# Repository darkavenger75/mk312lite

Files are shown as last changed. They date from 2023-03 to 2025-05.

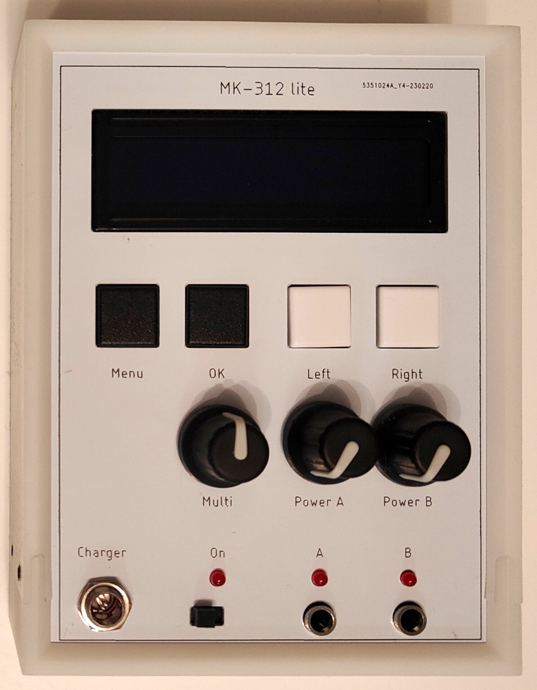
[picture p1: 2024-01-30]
images/mk312lite_case.jpg

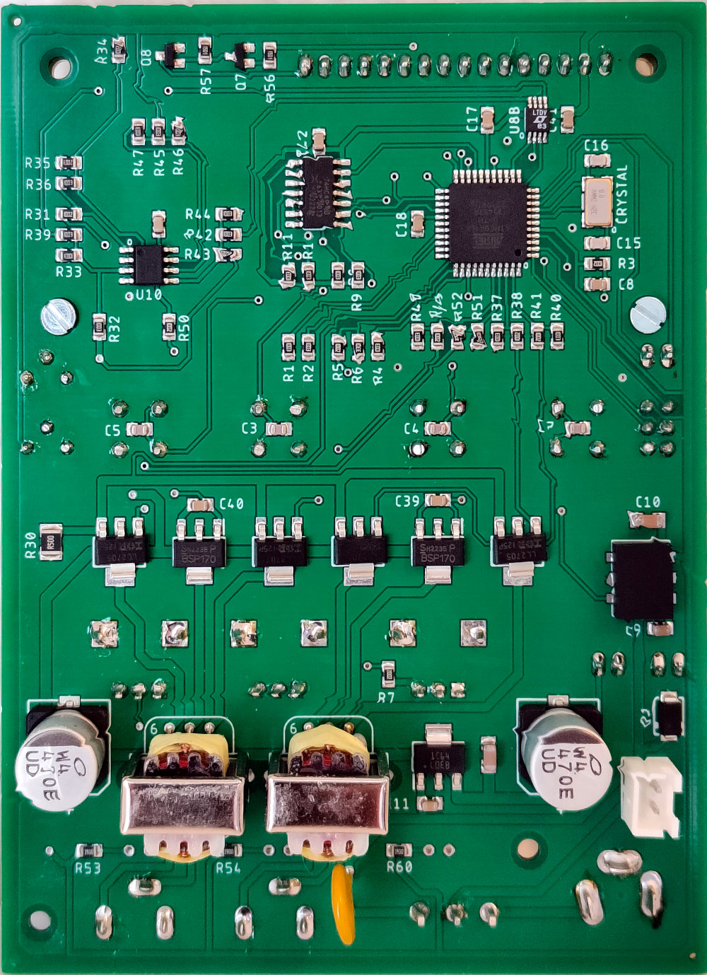
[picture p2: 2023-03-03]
images/mk312lite_pcb_back.jpg

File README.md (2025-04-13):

# mk-312 lite

## Introduction

A smaller, lighter, cheaper and easier to assemble version of the mk-312 with most of its functionality

- LiFePO4 instead of Pb battery
- 90 x 120 mm single PCB design
- Most components SMT (JLCPCB will do most of the work)
- No inputs, though

## Board ordering instructions

PCB
- Default settings by JLCPCB work fine. Feel free to choose different color, etc. Lead-free recommended for the sake of the environment.

Front panel
- 1.2 mm aluminium, black or white. 

Assembly
- Economic, Bottom side, as many PCBs as you wish. "Confirm Parts Placement" recommended. 
- Automatic selection of parts after uploading BOM and CPL worked well, but better check for errors. 
- Check part placement and rotation, esp. ATmega, transistors and 5V DC/DC converter (K7805).  

## Parts ordering information

You will in addition require all pin-through-hole parts, they are included in the BOM (V4), though. Do not forget the buttom covers and knobs for the potentiometers. 
In addition, you will have to order
- A 12V 2Ah LiFePo4 4-cell battery with BMS and connector matching the one you used on the board. I got mine from Eremit in Germany. You can use a 3-cell LiPo battery pack instead (there is a LDO voltage regulator on the 9V rail), but the R5/R6 voltage divider must be adjusted to avoid incorrect low battery warning/shutdown.
- A matching external CHARGER for your battery pack with 5.5/2.1 mm connector, center positive. Do NOT just connect a power supply without current limiter.   

## Board assembly Instructions

- The two transformers, battery connector and polyfuse (if not SMT) go to the bottom of the PCB (or the front panel will not fit).
- Best shorten the spindels of the pots beforehand, if you bought the 20 mm version. Also shorten/remove the taps.  
- The connectors and LEDs are best soldered with the front panel attached such that they fit neatly into the respective holes. 
- Ensure polarity of your battery pack and charger is correct, or things may get fried. 

## Firmware

The firmware has not been modified, for instructions see the "firmware" folder. 

## Case

The front panel goes directly on top of the PCB. Use washers on the pots to level the front panel as required.  
Bottom closes with plain aluminum panel.  
A simple 3D printed case - two halves which close by 4 pins or headless screws - can be found in the "case" directory.

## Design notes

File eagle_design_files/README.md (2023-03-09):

EAGLE board, schematic and front panel for the mk-312 lite fun box.

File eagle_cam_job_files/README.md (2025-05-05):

Files for PCB production and SMT assembly by JLCPCB 

Gerber file:           JLC_gerber.zip

BOM, bottom, SMT only: JLC_BOM.csv

Pick-and-place:        JLC_CPL.csv

Make sure to check placement/orientation of SMT components when ordering an already assembled board!

Full BOM:              mk312lite_V2_full_BOM.csv 

Anything that has an entry in the "Description" column is pin-through-hole and has to be ordered separately. 

Front panel, Gerber:   JLC_gerber_front.zip (fitting a 71*24 mm display)

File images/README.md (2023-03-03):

Photos of the PCB and the assembled device.

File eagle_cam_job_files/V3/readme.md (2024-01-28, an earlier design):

## Update
- BOM edited to include JLCPCB part numbers such that automatic part selection should work from the start
- CPL edited to fix rotation of components
- Some extended parts replaced by basic parts for lower cost. Further cost reduction by replacing the logic-level MOSFETs IRLL2705 by AO3400 possible. 
- Display brightness pot removed due to being ineffective

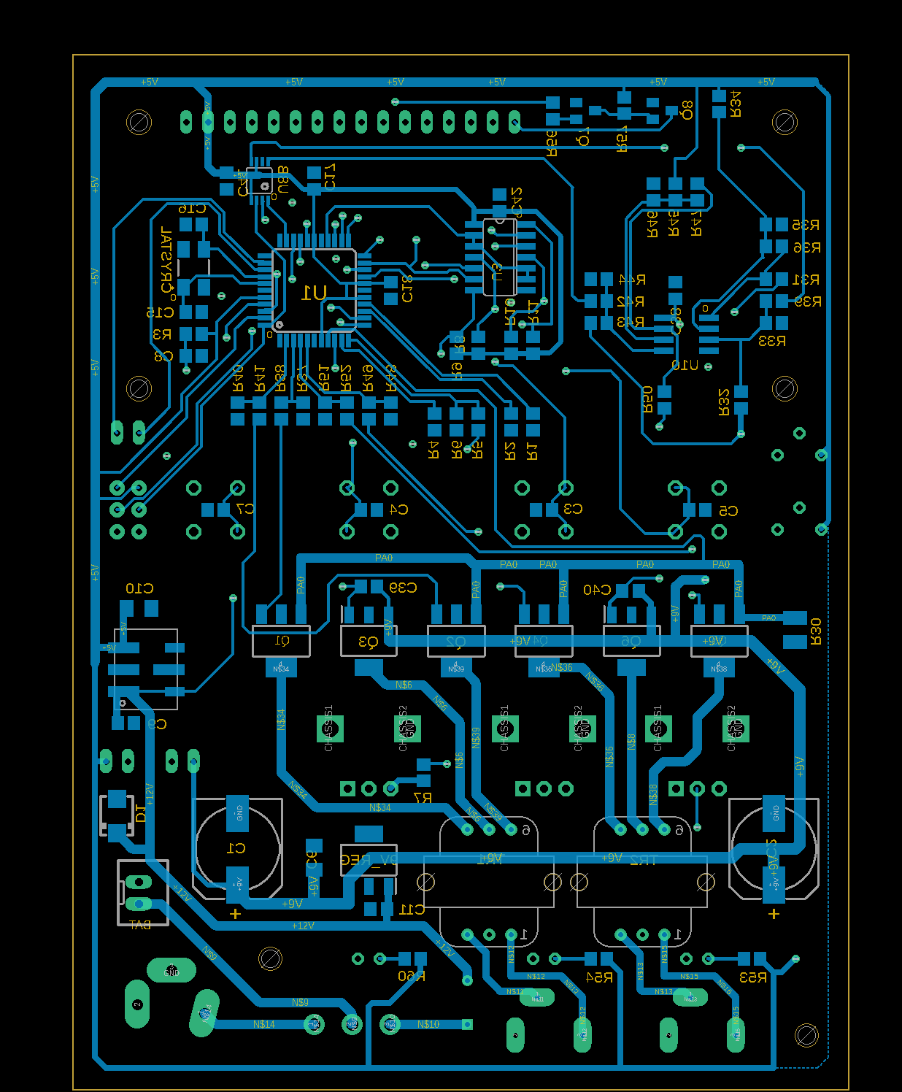
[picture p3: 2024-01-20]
eagle_design_files/mk312lite_V2_Bottom.png

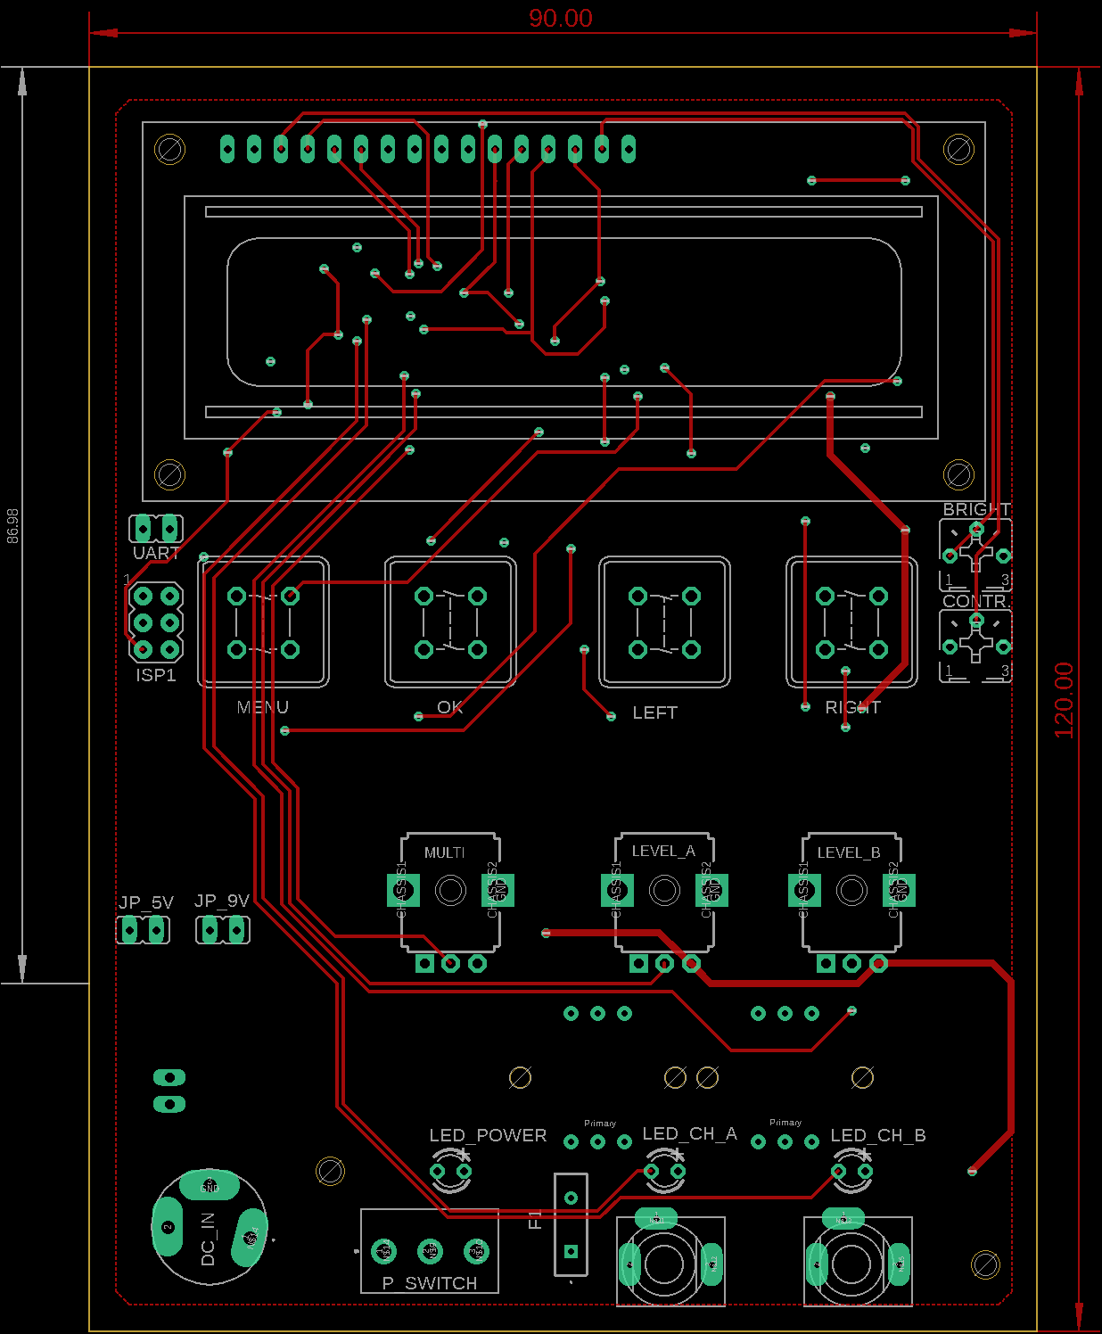
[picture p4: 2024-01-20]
eagle_design_files/mk312lite_V2_Top.png

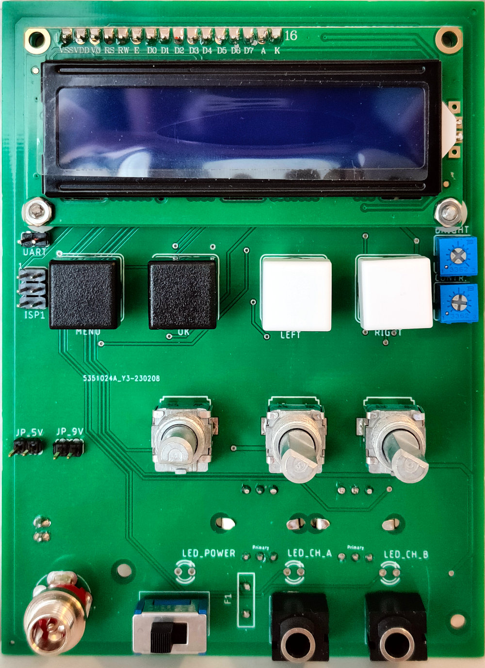
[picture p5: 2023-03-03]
images/mk312lite_pcb_front.jpg

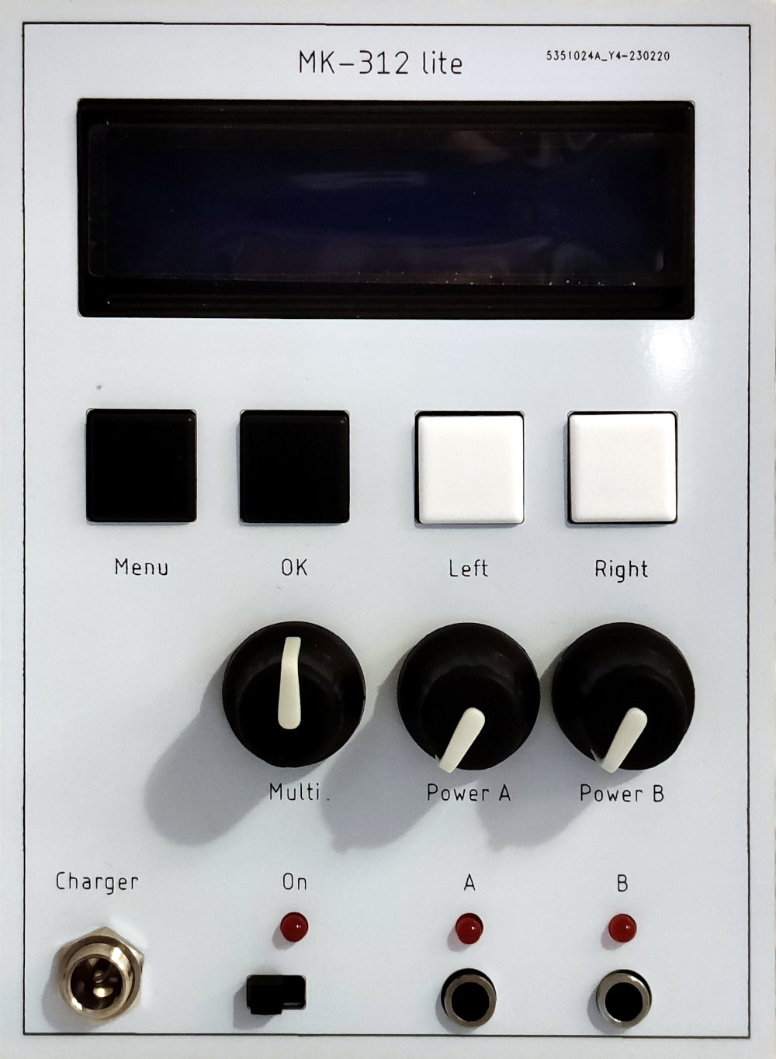
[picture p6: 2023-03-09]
images/mk312lite_front.jpg

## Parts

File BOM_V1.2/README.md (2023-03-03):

Old BOM of version 1.2. Might contain additional useful information on the required PTH components.

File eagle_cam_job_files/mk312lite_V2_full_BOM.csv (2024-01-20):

Part | Value | Device | Package | Description
9V_REG | LM2940IMP-9.0/NOPB | LM2940IMP-9.0_NOPB | SOT230P700X180-4N
BAT | B2B-XH-A-GU | JST-XH-02-PIN-LONG-PAD | JST-XH-02-PACKAGE-LONG-PAD | JST XH Connector 2 Pin (battery connector)
C1 | 470uF | CPOL-EU150CLZ-1010 | 150CLZ-1010
C2 | 470uF | CPOL-EU150CLZ-1010 | 150CLZ-1010
C3 | 100pF | C-EUC0805 | C0805
C4 | 100pF | C-EUC0805 | C0805
C5 | 100pF | C-EUC0805 | C0805
C6 | 22uF | C-EUC1206 | C1206
C7 | 100pF | C-EUC0805 | C0805
C8 | 0.1uF | C-EUC0805 | C0805
C9 | 10uF | C-EUC0805 | C0805
C10 | 22uF | C-EUC1206 | C1206
C11 | 0.47uF | C-EUC0805 | C0805
C15 | 20pF | C-EUC0603 | C0603
C16 | 20pF | C-EUC0603 | C0603
C17 | 0.1uF | C-EUC0805 | C0805
C18 | 0.1uF | C-EUC0805 | C0805
C38 | 0.1uF | C-EUC0805 | C0805
C39 | 0.1uF | C-EUC0805 | C0805
C40 | 0.1uF | C-EUC0805 | C0805
C41 | 0.1uF | C-EUC0805 | C0805
C42 | 0.1uF | C-EUC0805 | C0805
CHAN_A | PJ-301C | PC-301C | PJ-301C | 1/8“ phone connector, mono, XKB
CHAN_B | PJ-301C | PC-301C | PJ-301C | 1/8“ phone connector, mono, XKB
CONTR. | 10k | TRIM_US-B25P | B25P | Bourns 3362P
CRYSTAL | 8MHZ | X2-SMD-5.0X3.2X1.3MM | Seed
D1 | S1M | S1M | SMA
DC_IN | PC721A | PC721A | PC721A | 5.5 / 2.1 mm DC connector
F1 | RHEF100 | RHEF100-2 | RHEF1002 | PTC Resettable Fuse 1A 30V
ISP1 | AVRISP-6 | AVRISP-6 | AVRISP | AVR ISP HEADER
JP_5V | +5V | JP1E | JP1 | JUMPER (optional)
JP_9V | +9V | JP1E | JP1 | JUMPER (optional)
LCD1 | HD44780LCD-1602 | HD44780LCD-1602 | LCD1602 | HD44780 LCD, 2 rows, 16 chars, e.g. Adafruit 181
LED_CH_A | OUTPUT A | LED3MM | LED3MM | LED
LED_CH_B | OUTPUT B | LED3MM | LED3MM | LED
LED_POWER | POWER | LED3MM | LED3MM | LED
LEFT | LEFT/DOWN | DTE6K | DTE6K | ITT SWITCH, buttom cover: BTND610F
LEVEL_A | RK09L1140A2U 10k | 9MM_SNAP-IN_POT_CHASSIS | 9MM_SNAP-IN_POT | 9mm vertical snap-in pot, Alpha / Panasonic style, knob BA761 / alternative RK09L1140A5L
LEVEL_B | RK09L1140A2U 10k | 9MM_SNAP-IN_POT_CHASSIS | 9MM_SNAP-IN_POT | 9mm vertical snap-in pot, Alpha / Panasonic style, knob BA761 / alternative RK09L1140A5L
MENU | MENU | DTE6K | DTE6K | ITT SWITCH, buttom cover: BTND600F
MULTI | RK09L114001E 10k | 9MM_SNAP-IN_POT_CHASSIS | 9MM_SNAP-IN_POT | 9mm vertical snap-in pot, Alpha / Panasonic style, knob BA761
OK | OK | DTE6K | DTE6K | ITT SWITCH, buttom cover: BTND600F
P_SWITCH | 8SS1012-Z | 8SS1012-Z | 8SS1012Z | NIDEC COPAL ELECTRONICS - 8SS1012-Z - SLIDE SWITCH, SPDT, 6A, 125VAC, TH
Q1 | IRLL2705P | N-HEXFET-2D_SOT232-IRLL2705 | SOT223
Q2 | IRLL2705P | N-HEXFET-2D_SOT232-IRLL2705 | SOT223
Q3 | BSP170PH6327 | IRFL9014TRPBF | SOT230P700X180-4N
Q4 | IRLL2705P | N-HEXFET-2D_SOT232-IRLL2705 | SOT223
Q5 | IRLL2705P | N-HEXFET-2D_SOT232-IRLL2705 | SOT223
Q6 | BSP170PH6327 | IRFL9014TRPBF | SOT230P700X180-4N
Q7 | MMBT3904 | MMBT3904LT1-NPN-SOT23-BEC | SOT23-BEC
Q8 | MMBT3904 | MMBT3904LT1-NPN-SOT23-BEC | SOT23-BEC
R1 | 100k | R-EU_R0805 | R0805
R2 | 100k | R-EU_R0805 | R0805
R3 | 10K | R-EU_R0805 | R0805
R4 | 100k | R-EU_R0805 | R0805
R5 | 10K | R-EU_R0805 | R0805
R6 | 3.3K | R-EU_R0805 | R0805
R7 | 20k | R-EU_R0805 | R0805
R8 | 100k | R-EU_R0805 | R0805
R9 | 100k | R-EU_R0805 | R0805
R10 | 100k | R-EU_R0805 | R0805
R11 | 100k | R-EU_R0805 | R0805
R12 | 100R | R-EU_R0805 | R0805
R30 | 1R | R-EU_R1206 | R1206
R30_2 | 1R | R-EU_R1206 | R1206
R31 | 100K | R-EU_R0805 | R0805
R32 | 100K | R-EU_R0805 | R0805
R33 | 100K | R-EU_R0805 | R0805
R34 | 100K | R-EU_R0805 | R0805
R35 | 200K | R-EU_R0805 | R0805
R36 | 100K | R-EU_R0805 | R0805
R37 | 100K | R-EU_R0805 | R0805
R38 | 10K | R-EU_R0805 | R0805
R39 | 10K | R-EU_R0805 | R0805
R40 | 100K | R-EU_R0805 | R0805
R41 | 10K | R-EU_R0805 | R0805
R42 | 100K | R-EU_R0805 | R0805
R43 | 100K | R-EU_R0805 | R0805
R44 | 100K | R-EU_R0805 | R0805
R45 | 100K | R-EU_R0805 | R0805
R46 | 200K | R-EU_R0805 | R0805
R47 | 100K | R-EU_R0805 | R0805
R48 | 100K | R-EU_R0805 | R0805
R49 | 10K | R-EU_R0805 | R0805
R50 | 10K | R-EU_R0805 | R0805
R51 | 100K | R-EU_R0805 | R0805
R52 | 10K | R-EU_R0805 | R0805
R53 | 390 | R-EU_R0805 | R0805
R54 | 390 | R-EU_R0805 | R0805
R56 | 1.5K | R-EU_R0805 | R0805
R57 | 1.5K | R-EU_R0805 | R0805
R60 | 390 | R-EU_R0805 | R0805
RIGHT | RIGHT/UP | DTE6K | DTE6K | ITT SWITCH, buttom cover: BTND610F
TR1 | 42TL004 | 42TL023 | 42TL | Xicon Micro-Mini EI-12 Audio Transformers 42TL/42TC/42TM Series
TR2 | 42TL004 | 42TL023 | 42TL | Xicon Micro-Mini EI-12 Audio Transformers 42TL/42TC/42TM Series
U$1 | K7805MT-500R4 | K7805MT-500R4 | DFN
U1 | ATMEGA16A | MEGA16-A | TQFP44
U3 | 4066D | 4066D | SO14
U8B | LTC1661 | LTC1661IMS8 | MSOP8
U10 | LM358D | LM358D | SO08
UART |  | JP1E | JP1 | JUMPER (optional)

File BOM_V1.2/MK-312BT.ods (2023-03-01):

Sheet: INFO
MK-312 BT V1.2 Information
Github Project Home : https://git.io/vMPVF
About
INFO is this Google Sheet - the latest copy of this document lives at http://tinyurl.com/mk312bt-info or https://goo.gl/Ia0wMW
FULLBOM consists of all items - sorted for sanity. Enter the number of units you want to produce in the top row and it will math for you.
MOUSERBOM1 contains items in FULL_BOM available from mouser and we select the "recommended" options . This BOM is for 1 UNIT.
NONMOUSER is a list of all the parts you cant get from Mouser with links to where you can get them from
RAWBOM is the output Eagle generates for the V1.1 schematic. This is used for cross checking the other documents.
MK-312BT V1.2 - Hardware Improvements over original ET-312B
1) Line input modified for matched frequency and level response on left and right channels.
2) Link I/O circuitry replaced with MAX-232CPE For better compatibility (True RS-232 Levels)
3) Provisions for Bluetooth radio, Radio takes over Link I/O when nothing is in the jack
4) New one piece front panel design where LCD, buttons, potentiometers, and LEDs are on the sub panel. Jacks and power switch on mainboard. Cleaner looking design with controls and jacks on 3/4" centers
5) Remote input added to facilitate DC response into B channel without compromising line audio input characteristics. Tip is voltage coming from remote 0-2 volts, Ring supplies 2 volts from a resistor divider internal to the unit. Sleeve is ground. The Remote is meant for the Audio 1 & 2 modes. External potentiometer and push button recommended for remote. Other SPST type of items can be used such as motion detectors with dry contact output or mercury switches.
6) Support for tri polar (+, GND, -) toys on the output channels
MK-312BT Hardware Jumper Settings
1) JP6 and JP7 [DISABLED BY DEFAULT]
Enabling JP6 and JP7 allow the use of tripolar (+, GND, -) toys on the corresponding channels by connecting the center tap of the transformer to the stereo jack
WARNING : ENABLING JP6 and JP7 will cause mono plug toys to short the transformer !!
MK-312BT Hardware Assembly Notes / Tips - PLEASE READ -
1) Trim Potentiometer knobs to correct length
2) Use black permanent marker to black out front panel hole walls
3) Cut the tabs off of the base of the pots so the board sits flush with the display facade
4) To correctly fit LCD - solder header to LCD board first. Next insert LCD panel into front panel daughter board. Then put screws on front panel facade and finger tighten M2.5 screws first. Adjust positions as needed so everything lines up and sits well. Finally soldering LCD header to front panel daughter board.
5) Make sure Pin 32 (LED2) on the HC-05 module is actually soldered and making connection to the ZS-040 break out board or "Radio" LED may not function on the front panel
6) Be very careful not to bridge pins when soldering the LM 2941 (U14). Apply heat to 1 pad only and carefully apply solder. If a bridge occurs - remove the IC, clean the pads throughly with flux and solder wick and then retry. Pins 2 and 3 can be bridged because they are both ground. Ensure that no other pins are bridged. Check with multimeter continuity tester for bridges before power on!
8) Make sure to check the orientation of all electrolytic caps. (+) indicates the positive and a solid white "|" indicates the negative .
9) MAKE SURE YOUR POWER PLUG IS CENTER POSITIVE OR THINGS WILL GO BADLY. If you fuck up and plug in a reversed polarity supply - replace electrolytic caps C1 and C4.
10) Please remember to adjust the LCD contrast potentiometer - if incorrectly set the unit and backlight will power on but the interface will not be displayed.
11) Place transformers with P facing the output jacks (yes we are using the transformers "backwards" if you follow orientation given in the transformer datasheet )
12)Trim pins of 4066 IC (U3) Socket on the front panel board flush before soldering so buttons can clear. If the buttons still interfere, carefully disassemble the button and cut off the bit of the plastic housing that interferes with the 4066 IC socket pins.
Changes made in buttshock-et312-frankenbutt f005 over original ET 312B V1.5/V1.6 firmware https://git.io/vMoHG
F005 Patches the following in addition to the stock firmware
1) changeversion: changes startup message from v1.6 to f005
2) unifyboxes: allow 1.5 and 1.6 boxes to share the same firmware
3) removerandomxor: box will always pick 0 as it's xor communication key
4) serialdumpmemory: box will allow serial to dump more of the flash memory on request
5) fixknobscaling: A and B levels now display smoothly 0-99 with no missing numbers
6) newmenu; adds a new sub menu "More Options", moves Link Slave to that menu
7) hookmain: adds a new mode "Random 3" kind of a combination of torment and random1 to the new options menu, adds a new mode "Random 4" which turns on with a random mode for 40ish seconds, then off for 20ish seconds
Modifying and Flashing Firmware onto ET312-BT
1) We are using an external 8mhz crystal instead of the internal RC oscillator that the original uses. We need to set the fuses to enable this. LOW FUSE : 0xFF HIGH FUSE : 0xDB
2) A patched version of buttshock-et312-frankenbutt-f005 is recommended .
3) Obtain or modify a copy of the firmware and flash the result onto the AVR.
5) If you dont want to use an external crystal - we need to set the calibration byte for the internal oscillator. If programming a blank chip you first need to read the calibration bytes of that part (i.e. using avrdude -t “dump calibration” the fourth byte is the calibration byte for 8MHz or use atmel studio to read the oscillator calibration byte). Then program that byte into 0x3fff in your firmware. These bytes will differ on different chips even from the same batch. The firmware reads that byte to set OSCCAL on startup. If the byte is inaccurate various problems and failures will occur related to timing, interrupts, and serial communication. Just use an external crystal dammit.
Errata and and Changes made from V1.0 to V1.1
1) C25 and C27 are mislabeled on the board, 1000pF is the correct value
2) R20 and R21 are mislabeled on the board, 100K is the correct value
3) R14 and R15 are mislabeled on the board, 1K is the correct value
4) R20 and R21 are mislabeled on the board, 20K is the correct value
5) Do not populate R9 100K
6) Do not populate R1B 12K
Errata and and Changes made from V1.1 to V1.2
1) Fixed routing error on display board.
2) Removed JP3 because pointless.
3) Changed size of electrolytics to make things fit a bit nicer.
Images of V1.2 MK 312BT
TODO : Changes to make for V1.3 MK 312BT
1) LM 2941 footprint to make it easier to solder without bridging
2) Move 4066 IC to better place.

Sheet: FULLBOM
Number of Units Produced : | 1
Designator | Description | Quantity per Unit | Total Quantity | Supplier | Supplier Part Number | Alternate Part | Notes
R55 | RES 47R | 1 | 1 | Mouser | 660-MF1/4DC47R0F
R53,R54,R59,R60 | RES 390R | 4 | 4 | Mouser | 660-MF1/4DCT52R3900F
C10,C11,C12,C13,C14,C17,C18,C19,C2,C21,C22,C23,C24,C26,C28,C29,C3,C32,C37,C38,C39,C40,C41,C42,C43,C44,C9 | CAP 0.1uF (0.1" spacing) 50V | 27 | 27 | Mouser | 80-C320C104K5R
R30 | RES 0.5R 1/2W | 1 | 1 | Mouser | 660-CF1/2CT52RR50J
R2 | RES 1.2K | 1 | 1 | Mouser | 660-MF1/4DCT52R1201F
R18, R56,R57 | RES 1.5K | 3 | 3 | Mouser | 660-MF1/4DCT52R1501F
C4,C5 | 1000uF 16V minimum | 2 | 2 | Mouser | 647-UPW1E102MPD6
R10,R20,R21,R27,R28,R29,R3,R31,R32,R33,R34,R36,R37,R40,R42,R43,R44,R45,R47,R48,R51 | RES 100K | 21 | 21 | Mouser | 660-MF1/4DC1003F
R38,R39,R41,R49,R5,R50,R52,R58 | RES 10K | 8 | 8 | Mouser | 660-MF1/4DCT52R1002F | 660-MF1/4DC1002F
C8 | CAP 10uF | 1 | 1 | Mouser | 647-USV1H100MFD1TP
C1 | CAP 10uF CER | 1 | 1 | Mouser | 810-FG11X7R1H106KRT6 |  | Ceramic Cap in case of reverse voltage dc supply
R1A | RES 12K | 1 | 1 | Mouser | 660-MF1/4DCT52R1202F
C15,C16 | CAP 18pF | 2 | 2 | Mouser | 80-C315C180J1G
F1 | 1A POLYFUSE | 1 | 1 | Mouser | 650-LVR100S
R14,R15,R19, | RES 1K | 3 | 3 | Mouser | 660-MF1/4DCT52R1001F
R12,R23,R25,R26 | RES 1M | 4 | 4 | Mouser | 660-MF1/4DCT52R1004F
D1 | DIODE 1N4004 | 1 | 1 | Mouser | 621-1N4004
D2,D3 | DIODE 1N4148 | 2 | 2 | Mouser | 512-1N4148
C25,C27 | CAP 1nF (0.1" spacing) | 2 | 2 | Mouser | 80-C315C102K1G
C20,C30,C31,C33,C34,C35,C36 | CAP 1uF (0.1" spacing) | 7 | 7 | Mouser | 80-C315C105K3R
R35,R46 | RES 200K | 2 | 2 | Mouser | 660-MF1/4DCT52R2003F
R11,R16,R17,R22,R24,R4 | RES 20K | 6 | 6 | Mouser | 660-MF1/4DCT52R2002F
J10,J11 | PAK100/2500-24 - 2425- 3M WALL HEADER | 2 | 2 | Mouser | 517-N2524-6002RB
Q7,Q8 | TRANS. 2N3904 | 2 | 2 | Mouser | 512-2N3904BU
R6 | RES 3.3K | 1 | 1 | Mouser | 660-MF1/4DCT52R3301F
R7,R8,R9 | RES 4.7K | 3 | 3 | Mouser | 660-MF1/4DCT52R4701F
U3 | CD4066N | 1 | 1 | Mouser | 595-CD4066BE
TR1,TR2 | 42TL004 | 2 | 2 | Mouser | 42TL004-RC
C6,C7 | CAP 470uF 16V | 2 | 2 | Mouser | 647-UHE1E471MPD
R13 | RES 47K | 1 | 1 | Mouser | 660-MF1/4DCT52R4702F
U13 | VREG 7805T | 1 | 1 | Mouser | 511-L7805CV | 511-L7805ACP | Alternate part is better thermally
U11,U12 | VREG 7809TV | 2 | 2 | Mouser | 511-L7809CV
XTAL1 | 8MHZ XTAL HC-49S | 1 | 1 | Mouser | 717-9B-8.000MEEJ-B
U1 | ATMEGA 16P | 1 | 1 | Mouser | 556-ATMEGA16A-PU | http://www.digikey.com/short/3fb4z5
LCD1 | LCD HD44780LCD-1602 | 1 | 1 | Mouser | 763-0216K1Z-NSW-BBW | 763-0216K1Z-NSW-FBW
Q3,Q6 | MOSFET IRF9Z24 | 2 | 2 | Mouser | 942-IRF9Z24NPBF
Q1,Q2,Q4,Q5 | MOSFET IRL520N | 4 | 4 | Mouser | 942-IRL520NPBF
JP1 | ISP 6 PIN | 1 | 1 | Mouser | 571-5-146254-3
U14 | LM2941 | 1 | 1 | Mouser | 926-LM2941CT/NOPB
U2 | LM324N | 1 | 1 | Mouser | 595-LM324N | 595-LM324NE3
U10,U4 | LM358N | 2 | 2 | Mouser | 512-LM358N
U8A (OPTIONAL - RECOMMEND USING U8B INSTEAD) | MAX548 | 0 | 0 | Mouser | 700-MAX548ACPA |  | For V1.5 and below firmware.We suggest using U8B LTC1661 purchased from Digikey (see below)
LED1,LED2,LED3,LED4 | 5MM LED | 4 | 4 | Mouser | 606-4304H1
U9 | MAX232 | 1 | 1 | Mouser | 700-MAX232CPE
SOCKET FOR U2,U3 | DIL 14 IC SOCKET | 2 | 2 | Mouser | 517-4814-3004-CP
SOCKET FOR U9 | DIL 16 IC SOCKET | 1 | 1 | Mouser | 517-4816-3004-CP
SOCKET FOR U1 | DIL 40 IC SOCKET | 1 | 1 | Mouser | 575-11041640410010
SOCKET FOR U10,U4,U8(A/B) | DIL 8 IC SOCKET | 4 | 4 | Mouser | 571-1-2199298-2
JP6,JP7 | 2x1 SIP HEADER 0.1" | 2 | 2 | Mouser | 571-5-146285-2
JUMPER | 0.1" JUMPER | 3 | 3 | Mouser | 571-382811-6
VR1, VR2 | ALPS 9mm 10K Pot | 2 | 2 | Mouser | 688-RK09L1140A2U
VR3 | ALPS 9mm 10K Dual Gang Pot | 1 | 1 | Mouser | 688-RK09L1240A12
VR4 | Bourns 3362P 10K Pot | 1 | 1 | Mouser | 3362P-1-103LF
S1,S2,S3,S4 | Buttons | 4 | 4 | Mouser | 611-D6C90F2LFS
J2,J3,J4,J5,J6,J7 | 3.5mm stereo jack | 6 | 6 | Mouser | 806-STX-3100-5NB
J8 | 2.1/5.5mm DC jack | 1 | 1 | Mouser | 490-PJ-002A
S5 | Toggle Switch with safety actuator | 1 | 1 | Mouser | 611-7101K2AV2BE | 611-7101K2AV2QE
J9 | Radio Header | 1 | 1 | Mouser | 538-90147-1206
PACTEC Case | Case | 1 | 1 | Mouser | 616-63025-510-000 | Suggest buying directly from PACTEC or sourcing a compatible case elsewhere http://bit.ly/2iuAHbB . UK SOURCE : http://uk.rs-online.com/web/p/consoles-desktop-enclosures/1047312/
Gray button covers | Button Cover | 2 | 2 | Mouser | 611-BTND610F | 611-BTND690F
White button covers | Button Cover | 2 | 2 | Mouser | 611-BTND600F
LCD HEADER | LCD Header | 1 | 1 | Mouser | 710-61301611121
KNOB | Potentiometer KNOB | 3 | 3 | Mouser | 450-BA761
BAT1 (Recommended Option) | Lead Acid Battery 2.5AH | 1 | 1 | Mouser | 547-PS-1220 | UK SOURCE http://uk.rs-online.com/web/p/lead-acid-rechargeable-batteries/5375444/
BAT1 (Option) | Lead Acid Battery 1.4AH | 0 | 0 | Mouser | 547-PS-1212
BAT 1 LUGS | Lugs For Connecting to BAT1 | 2 | 2 | Mouser | 534-8291 |  | Crimp on Lugs for Battery
Power Supply 15V (Option) | 15V, > 1A , 5.5MM OD Plug | 0 | 0 | Mouser | 709-GST25U15-P1J
Power Supply 18 V (Recommended Option) | 18V, 1A , 5.5MM OD Plug | 1 | 1 | Mouser | 709-GST18U18-P1J |  | Suggest using 18V version to give linear regulator a bit more headroom . 15V will *just barely* work
IDC connectors for ribbon cable | Ribbon Cable Connector(or buy a ready made cable) | 2 | 2 | Mouser | 517-8924 |  | Suggest sourcing a ready made cable . See misc hardware below
24 conductor ribbon cable | Bare Ribbon Cable (or buy a ready made cable) | 1 | 1 | Mouser | 517-3365/24-100 |  | See above.
Radio | HC-05 Bluetooth Module | 1 | 1 | Amazon | HC-05 (multiple amazon vendors) |  | http://amzn.to/2iiOXz6
U8B | LTC1661 (For V1.6 and above firmware) | 1 | 1 | Digikey | LTC1661CN8#PBF-ND |  | This is the suggested DAC
J1 T Connector (Deans Connector)- DNF (Unless you want to , then F away) | 12V Battery Connector | 1 | 1 | Hobbyking | SKU: 015000231-0 |  | http://bit.ly/2jpP4gQ
MISC HARDWARE
Ribbon Cable 24 pin, 2.54mm pitch IDC. | Ribbon Cable | 1 | 1 | Amazon | B01BGNLPX0 |  | http://amzn.to/2jp34ay
#4 x 1/4" sheet metal screw (Main board to case) | Screw | 2 | 2 | McMaster-Carr | 90190A106 |  | http://bit.ly/2jCJuVR
M2.5 x 20mm socket head screw (Front panel screws) | Screw | 6 | 6 | McMaster-Carr | 91290A108 |  | http://bit.ly/2jhEohH
M2.5 nut (Front panel nut) | Screw | 22 | 22 | McMaster-Carr | 90591A270 |  | http://bit.ly/2jpf0Jq
18 Gauge Wire : | Battery Leads (quantity ft) | 5 | 5 | McMaster-Carr | 8054T15 |  | http://bit.ly/2jCHwER
Heat Shrink | Heat Shrink Tubing | 1 | 1 | McMaster-Carr | 7496K43 |  | http://bit.ly/2jYteSl

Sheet: MOUSERBOM1
Designator | Description | Quantity per Unit | Supplier | Supplier Part Number | Mfg Part Number | Alternate Part
R55 | RES 47R | 1 | Mouser | 660-MF1/4DC47R0F | MF1/4DC47R0F
R53,R54,R59,R60 | RES 390R | 4 | Mouser | 660-MF1/4DCT52R3900F | MF1/4DCT52R3900F
C10,C11,C12,C13,C14,C17,C18,C19,C2,C21,C22,C23,C24,C26,C28,C29,C3,C32,C37,C38,C39,C40,C41,C42,C43,C44,C9 | CAP 0.1uF (0.1" spacing) 50V | 27 | Mouser | 80-C320C104K5R | C320C104K5R5TA
R30 | RES 0.5R 1/2W | 1 | Mouser | 660-CF1/2CT52RR50J | CF1/2CT52RR50J
R2 | RES 1.2K | 1 | Mouser | 660-MF1/4DCT52R1201F | MF1/4DCT52R1201F
R18, R56,R57 | RES 1.5K | 3 | Mouser | 660-MF1/4DCT52R1501F | MF1/4DCT52R1501F
C4,C5 | 1000uF 16V minimum | 2 | Mouser | 647-UPW1E102MPD6 | UPW1E102MPD6
R10,R20,R21,R27,R28,R29,R3,R31,R32,R33,R34,R36,R37,R40,R42,R43,R44,R45,R47,R48,R51 | RES 100K | 21 | Mouser | 660-MF1/4DC1003F | MF1/4DC1003F
R38,R39,R41,R49,R5,R50,R52,R58 | RES 10K | 8 | Mouser | 660-MF1/4DC1002F | MF1/4DC1002F | 660-MF1/4DCT52R1002F
C8 | CAP 10uF | 1 | Mouser | 647-USV1H100MFD1TP | USV1H100MFD1TP
C1 | CAP 10uF CER | 1 | Mouser | 810-FG11X7R1H106KRT6 | FG11X7R1H106KRT06
R1A | RES 12K | 1 | Mouser | 660-MF1/4DCT52R1202F | MF1/4DCT52R1202F
C15,C16 | CAP 18pF | 2 | Mouser | 80-C315C180J1G | C315C180J1G5TA
F1 | 1A POLYFUSE | 1 | Mouser | 650-LVR100S | LVR100S
R14,R15,R19, | RES 1K | 3 | Mouser | 660-MF1/4DCT52R1001F | MF1/4DCT52R1001F
R12,R23,R25,R26 | RES 1M | 4 | Mouser | 660-MF1/4DCT52R1004F | MF1/4DCT52R1004F
D1 | DIODE 1N4004 | 1 | Mouser | 621-1N4004 | 1N4004-T
D2,D3 | DIODE 1N4148 | 2 | Mouser | 512-1N4148 | 1N4148
C25,C27 | CAP 1nF (0.1" spacing) | 2 | Mouser | 80-C315C102K1G | C315C102K1G5TA
C20,C30,C31,C33,C34,C35,C36 | CAP 1uF (0.1" spacing) | 7 | Mouser | 80-C315C105K3R | C315C105K3R5TA
R35,R46 | RES 200K | 2 | Mouser | 660-MF1/4DCT52R2003F | MF1/4DCT52R2003F
R11,R16,R17,R22,R24,R4 | RES 20K | 6 | Mouser | 660-MF1/4DCT52R2002F | MF1/4DCT52R2002F
J10,J11 | PAK100/2500-24 - 2425- 3M WALL HEADER | 2 | Mouser | 517-N2524-6002RB | N2524-6002RB
Q7,Q8 | TRANS. 2N3904 | 2 | Mouser | 512-2N3904BU | 2N3904BU
R6 | RES 3.3K | 1 | Mouser | 660-MF1/4DCT52R3301F | MF1/4DCT52R3301F
R7,R8,R9 | RES 4.7K | 3 | Mouser | 660-MF1/4DCT52R4701F | MF1/4DCT52R4701F
U3 | CD4066N | 1 | Mouser | 595-CD4066BE | CD4066BE
TR1,TR2 | 42TL004 | 2 | Mouser | 42TL004-RC | 42TL004-RC
C6,C7 | CAP 470uF 16V | 2 | Mouser | 647-UHE1E471MPD | UHE1E471MPD
R13 | RES 47K | 1 | Mouser | 660-MF1/4DCT52R4702F | MF1/4DCT52R4702F
U13 | VREG 7805T | 1 | Mouser | 511-L7805CV | L7805CV | 511-L7805ACP
U11,U12 | VREG 7809TV | 2 | Mouser | 511-L7809CV | L7809CV
XTAL1 | 8MHZ XTAL HC-49S | 1 | Mouser | 717-9B-8.000MEEJ-B | 9B-8.000MEEJ-B
U1 | ATMEGA 16P | 1 | Mouser | 556-ATMEGA16A-PU | ATMEGA16A-PU | 556-ATMEGA16L-8PU ELSE SEE DIGIKEY ON NONMOUSER
LCD1 | LCD HD44780LCD-1602 | 1 | Mouser | 763-0216K1Z-NSW-BBW | NHD-0216K1Z-NSW-FBW-L | 763-0216K1Z-NSW-FBW
Q3,Q6 | MOSFET IRF9Z24 | 2 | Mouser | 942-IRF9Z24NPBF | IRF9Z24NPBF
Q1,Q2,Q4,Q5 | MOSFET IRL520N | 4 | Mouser | 942-IRL520NPBF | IRL520NPBF
JP1 | ISP 6 PIN | 1 | Mouser | 571-5-146254-3 | 5-146254-3
U14 | LM2941 | 1 | Mouser | 926-LM2941CT/NOPB | LM2941CT/NOPB
U2 | LM324N | 1 | Mouser | 595-LM324NE3 | LM324NE3 | 595-LM324N
U10,U4 | LM358N | 2 | Mouser | 512-LM358N | LM358N
U8A | MAX548 (For V1.5 and below firmware) suggest using LTC1661 purchased from Digikey (see end of sheet) | 0 | Mouser | 700-MAX548ACPA | MAX548ACPA+
LED1,LED2,LED3,LED4 | 5MM LED | 4 | Mouser | 606-4304H1 | 4304H1
U9 | MAX232 | 1 | Mouser | 700-MAX232CPE | MAX232CPE
SOCKET FOR U2,U3 | DIL 14 IC SOCKET | 2 | Mouser | 517-4814-3004-CP | 4814-3004-CP
SOCKET FOR U9 | DIL 16 IC SOCKET | 1 | Mouser | 517-4816-3004-CP | 4816-3004-CP
SOCKET FOR U1 | DIL 40 IC SOCKET | 1 | Mouser | 575-11041640410010 | 110-41-640-41-001000
SOCKET FOR U10,U4,U8(A/B) | DIL 8 IC SOCKET | 4 | Mouser | 571-1-2199298-2 | 1-2199298-2
JP6,JP7 | 2x1 SIP HEADER 0.1 | 2 | Mouser | 571-5-146285-2 | 5-146285-2
VR1, VR2 | ALPS 9mm 10K Pot | 2 | Mouser | 688-RK09L1140A2U | RK09L1140A2U
VR3 | ALPS 9mm 10K Dual Gang Pot | 1 | Mouser | 688-RK09L1240A12 | RK09L1240A12
VR4 | Bourns 3362P 10K Pot | 1 | Mouser | 3362P-1-103LF | 3362P-1-103LF
S1,S2,S3,S4 | Buttons | 4 | Mouser | 611-D6C90F2LFS | D6C90 F2 LFS
J2,J3,J4,J5,J6,J7 | 3.5mm stereo jack | 6 | Mouser | 806-STX-3100-5NB | STX-3100-5NB
J8 | 2.1/5.5mm DC jack | 1 | Mouser | 490-PJ-002A | PJ-002A
S5 | Toggle Switch with safety actuator | 1 | Mouser | 611-7101K2AV2BE | 7101K2AV2BE | 611-7101K2AV2QE
J9 | Radio Header | 1 | Mouser | 538-90147-1206 | 90147-1206
Gray button covers | Button Cover | 2 | Mouser | 611-BTND610F | BTND610F | 611-BTND690F
White button covers | Button Cover | 2 | Mouser | 611-BTND600F | BTN D6 00 F
LCD HEADER | LCD Header | 1 | Mouser | 710-61301611121 | 61301611121
Knob | Potentiometer Knob | 3 | Mouser | 450-BA761 | BA761
BAT1 | Lead Acid Battery | 1 | Mouser | 547-PS-1220 | PS-1220
BAT1 Lugs | Crimp Lubs for BAT1 | 2 | Mouser | 534-8291 | 534-8291
Power Supply | 18V, 1A .5.5mm OD plug | 1 | Mouser | 709-GST18U18-P1J | GST18U18-P1J | 709-GST25U15-P1J

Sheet: NONMOUSER
Parts Not Sourced from Mouser
Part | Quantity
Bluetooth Radio HC - 05 | 1
Amazon : http://amzn.to/2l0UEoj
LTC 1661 DAC | 1
Digikey LTC1661CN8#PBF-ND : http://www.digikey.com/short/3rh0zq
LM324N (Digikey if mouser is out of stock)
Digikey : http://www.digikey.com/short/3fb4md | 1
ATMEGA 16 (Digikey if mouser is out of stock)
Digikey : http://www.digikey.com/short/3fb4z5 | 1
Ribbon Cable 24 pin, 2.54mm pitch IDC. | 1
Amazon : http://amzn.to/2jp34ay
18 Gauge Wire : | 5ft
McMaster-Carr: http://bit.ly/2jCHwER
Heat Shrink Tubing: | 1 pack
McMaster-Carr : http://bit.ly/2jYteSl
#4 x 1/4" sheet metal screw (Main board to case) | 2
McMaster-Carr : http://bit.ly/2jCJuVR
M2.5 x 20mm socket head screw (Front panel screws) | 6
McMaster-Carr : http://bit.ly/2jhEohH
M2.5 nut (Front panel nut) | 22
McMaster-Carr : http://bit.ly/2jpf0Jq
T Connector (Deans Connector - OPTIONAL) | 1
Hobbyking : http://bit.ly/2jpP4gQ
Lead Acid Battery
Digikey : https://www.digikey.com/short/3ff7t4
Pactec Case | 1
Allied : http://www.alliedelec.com/pactec-cm86-225-000-k/70080019/
Pactec : https://www.pactecenclosures.com/product-detail.php?productid=72&classid=26&seriesid=45
UK Souce RS Online : http://uk.rs-online.com/web/p/consoles-desktop-enclosures/1047312/
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

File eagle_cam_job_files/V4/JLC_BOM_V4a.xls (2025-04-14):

Comment | Designator | Footprint | JLCPCB Part #
IRLL2705 | Q1,Q2,Q4,Q5 | SOT223 | C151552
3.3K | R6 | R0805 | C26010
100K | R1,R2,R4,R8,R9,R10,R11,R31,R32,R33,R34,R36,R37,R40,R42,R43,R44,R45,R47,R48,R51 | R0805 | C149504
10K | R3,R5,R38,R39,R41,R49,R50,R52 | R0805 | C17414
100pF | C3,C4,C5,C7 | C0805 | C1790
1.5K | R56,R57 | R0805 | C4310
470uF | C1,C2 | 150CLZ-1010 | C125983
1R | R30,R30_2 | R1206 | C17928
20k | R7 | R0805 | C4328
0.47uF | C11 | C0805 | C13967
22uF | C6,C10,C12,C13,C14 | C1206 | C12891
8MHz | Y1 | X2-SMD-5.0X3.2X1.3MM | C115962
20pF | C15,C16 | C0603 | C1648
LM358D | U10 | SO08 | C7950
LM2940IMP-9.0/NOPB | 9V_REG | SOT230P700X180-4N | C471057
BSP170PH6327 | Q3,Q6 | SOT230P700X180-4N | C75283
MMBT3904 | Q7,Q8 | SOT23-BEC | C20526
SS14 | D1,D2 | SMA | C2480
ATMEGA16A | U1 | TQFP44 | C5658
390 | R53,R54,R60 | R0805 | C17655
4066D | U3 | SO14 | C5628
200K | R35,R46 | R0805 | C17539
0.1uF | C8,C17,C18,C38,C39,C40,C41,C42 | C0805 | C49678
10nF | C9 | C0805 | C1710
LTC1661CMS | U8b | MOSP8 | C676323
100R | R12 | R0805 | C17408
SMD1812P110TF/33 | F1 | 1812 | C495358
LM2674 | IC1 | SO08 | C5563868
47uH | L1 | FNR4030S470MT | C167888
8SS1012-Z | P_SWITCH | 8SS1012Z | C2921507
10k | CONTR. | B25P | C58159
42TL004 | TR1 TR2 | 42TL
AVRISP-6 | ISP1 | 2x3P | C492420
B2B-XH-A-GU | BAT | JST-XH-02-PACKAGE-LONG-PAD | C495685
HD44780LCD-1602 | LCD1 | LCD1602
DTEK_PUSH | LEFT,MENU,OK,RIGHT | DTE6K | C2689630
LED_3mm_Red | LED_CH_A,LED_CH_B,LED_POWER | LED3MM | C3097768
PC721A | DC_IN | PC721A | C3094899
PJ-301C | CHAN_A CHAN_B | PJ-301C | C692433
RK09L1140A5L | LEVEL_A LEVEL_B | 9MM_SNAP-IN_POT | C7419101
RK09L114001E 10k | MULTI | 9MM_SNAP-IN_POT | C7497836
P_HEADER 1x2 | UART | 1x2P | C492401

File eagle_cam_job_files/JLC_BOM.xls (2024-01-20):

Comment | Designator | Footprint | JLCPCB Part #
IRLL2705P | Q1,Q2,Q4,Q5 | SOT223 | C151552
3.3K | R6 | R0805 | C26010
100K | R1,R2,R4,R8,R9,R10,R11,R31,R32,R33,R34,R36,R37,R40,R42,R43,R44,R45,R47,R48,R51 | R0805 | C149504
10K | R3,R5,R38,R39,R41,R49,R50,R52 | R0805 | C17414
100pF | C3,C4,C5,C7 | C0805 | C1790
1.5K | R56,R57 | R0805 | C4310
470uF | C1,C2 | 150CLZ-1010 | C125983
0.5R | R30 | R1210 | C473589
20k | R7 | R0805 | C4328
0.47uF | C11 | C0805 | C13967
22uF | C6,C10 | C1206 | C12891
ABMM2-8.000MHZ-E2-T | CRYSTAL | ABMM2 | C431529
18pF | C15,C16 | C0805 | C1797
LM358D | U10 | SO08 | C7950
LM2940IMP-9.0/NOPB | 9V_REG | SOT230P700X180-4N | C471057
10uF | C9 | C0805 | C15850
BSP170PH6327 | Q3,Q6 | SOT230P700X180-4N | C75283
MMBT3904 | Q7,Q8 | SOT23-BEC | C20526
K7805MT-500R4 | U$1 | DFN | C2684892
S1M | D1 | SMA | C412437
ATMEGA16A | U1 | TQFP44 | C5658
390 | R53,R54,R60 | R0805 | C17655
4066D | U3 | SO14 | C5628
200K | R35,R46 | R0805 | C17539
0.1uF | C8,C17,C18,C38,C39,C40,C41,C42 | C0805 | C49678
LTC1661CMS | U8b | MOSP8 | C676323

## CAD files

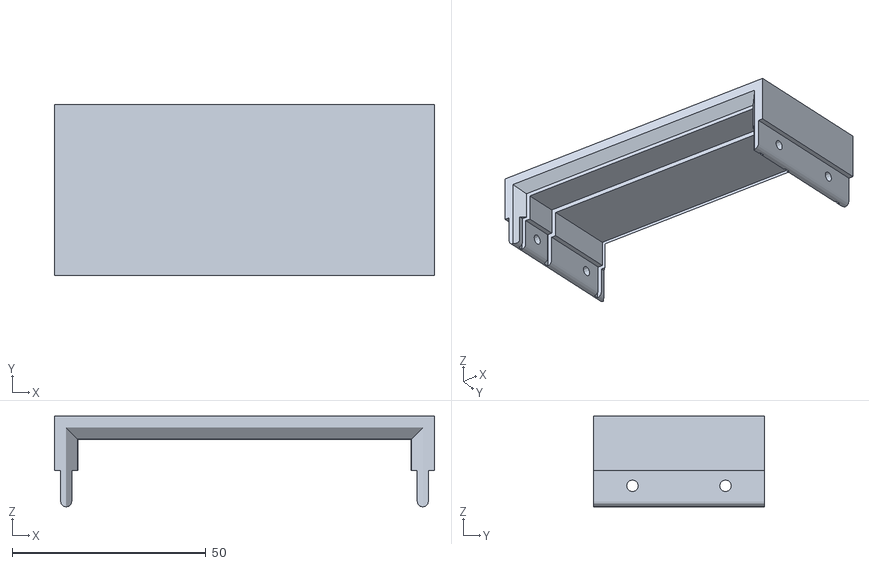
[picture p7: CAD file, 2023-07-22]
case/Case_312_JLC_P2.stl
98.0 x 44.0 x 23.5

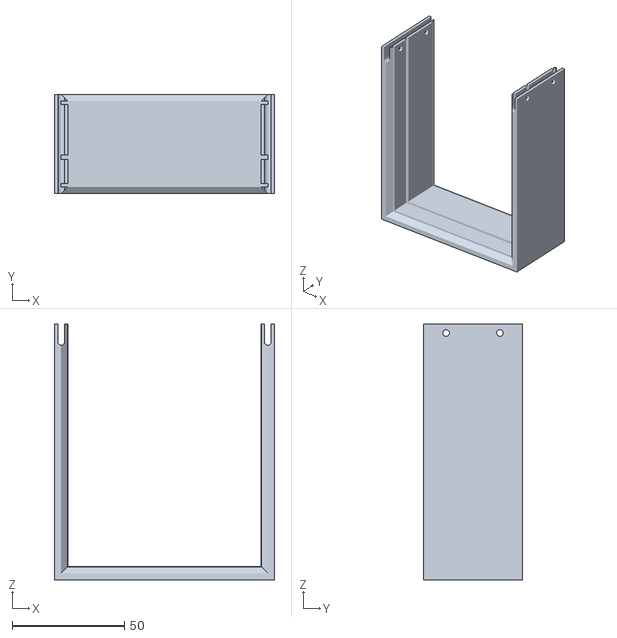
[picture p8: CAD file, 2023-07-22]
case/Case_312_JLC_P1.stl
98.0 x 44.0 x 114.0

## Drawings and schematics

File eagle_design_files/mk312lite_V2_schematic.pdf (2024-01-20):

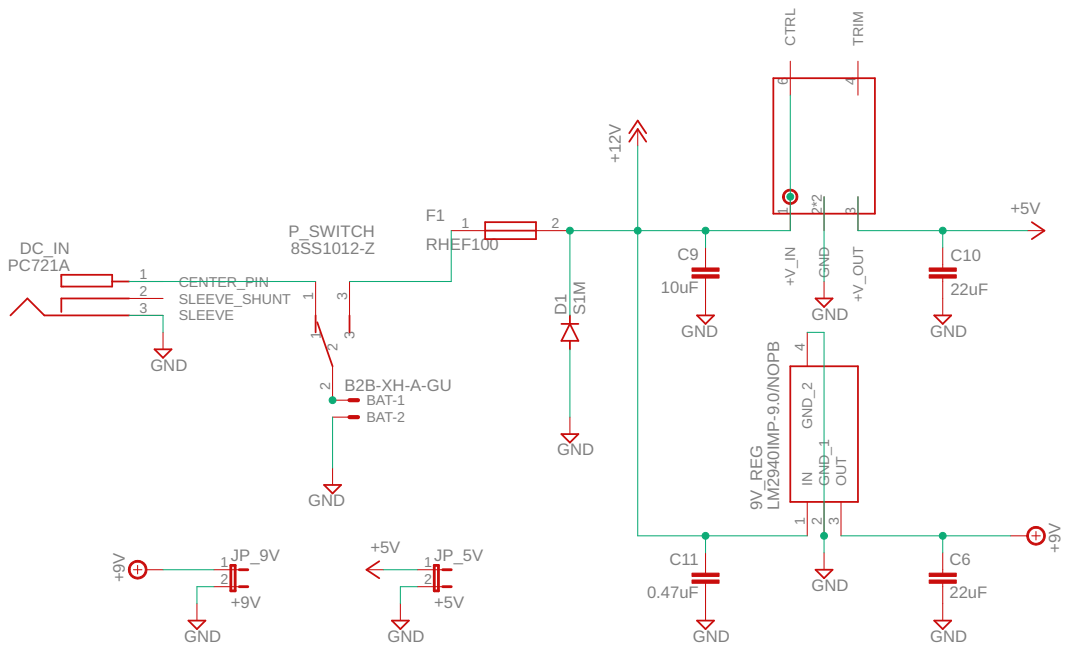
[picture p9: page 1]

Document Number: | REV:

Date: 04.03.2023 11:06 | Sheet: 1/4

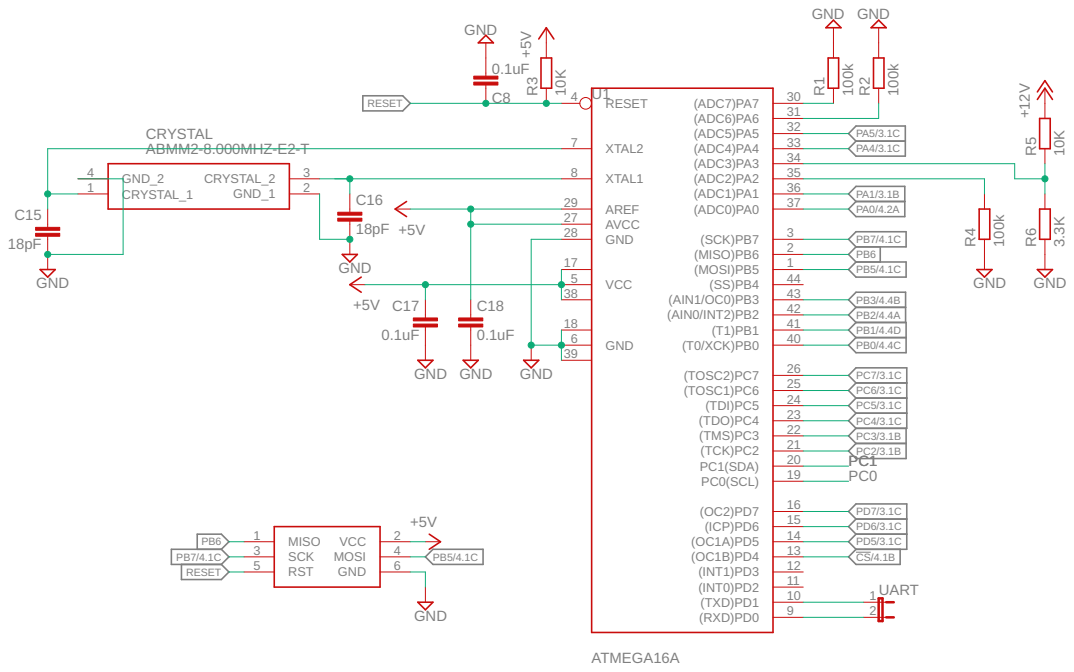
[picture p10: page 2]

6 | | 40
39

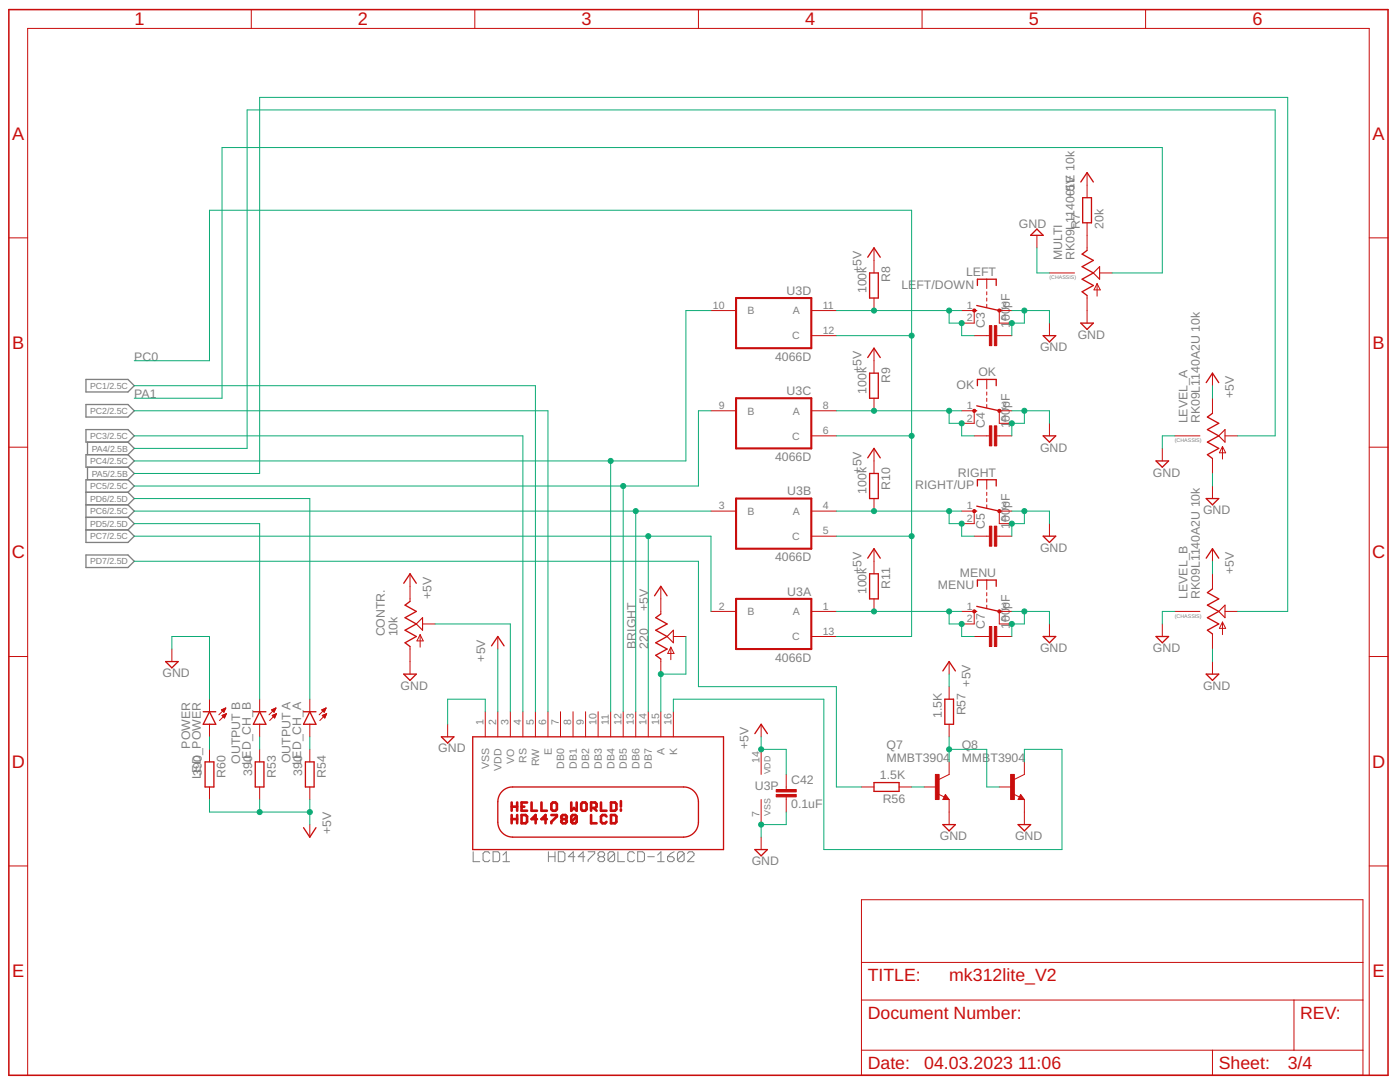
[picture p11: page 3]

RK09L1140A2U 10k RK09L1140A2U 10kRIGHT/UP MENU GND GND 10k +5+V5V +5V 390 390 +5V OUTPUT A OUTPUT B 4066D 4066D 4066D 4066D GND +5V LEFT/DOWNOK GND GND +5V GND GND +5V GND GND GND GND 0.1uF GND GND GND POWER 390MMBT3904 MMBT3904 1.5K 1.5K GND GND +5V 20k +5V 100pF 100pF 100pF 100pF 220 RK09L114001E 10k 100+k5V 100+k5V 100+k5V 100+k5V (CHASSIS) LEVEL_A (CHASSIS) LEVEL_B 1 3 2 4 RIGHT 1 3 2 4 MENU K 16 A 15 DB7 14 DB6 13 DB5 12 DB4 11 DB3 10 DB2 9 DB1 8 DB0 7 E 6 RW 5 RS 4 VO 3 VDD 2 VSS 1 CONTR. R54 R53LED_CH_A LED_CH_B A 1 B 2 C 13 U3A A 4 B 3 C 5 U3B A 8 B 9 C 6 U3CA 11 B 10 C 12 U3D VDD VSS 7 14 U3P 1 3 2 4 LEFT 1 3 2 4 OK C42 LED_POWER R60 Q7 Q8 R56 R57 R7 C3 C4 C5 C7 BRIGHT (CHASSIS) MULTI R8 R10 R11 R9 PC4/2.5C PC5/2.5C PC6/2.5C PC7/2.5C PC3/2.5C PC2/2.5C PC1/2.5C PD7/2.5D PD5/2.5D PD6/2.5D PC0 PA5/2.5B PA4/2.5B PA1 ABCDE ABCDE 1 2 3 4 5 6 Date: Sheet: REV: TITLE: Document Number: 04.03.2023 11:06 3/4 mk312lite_V2

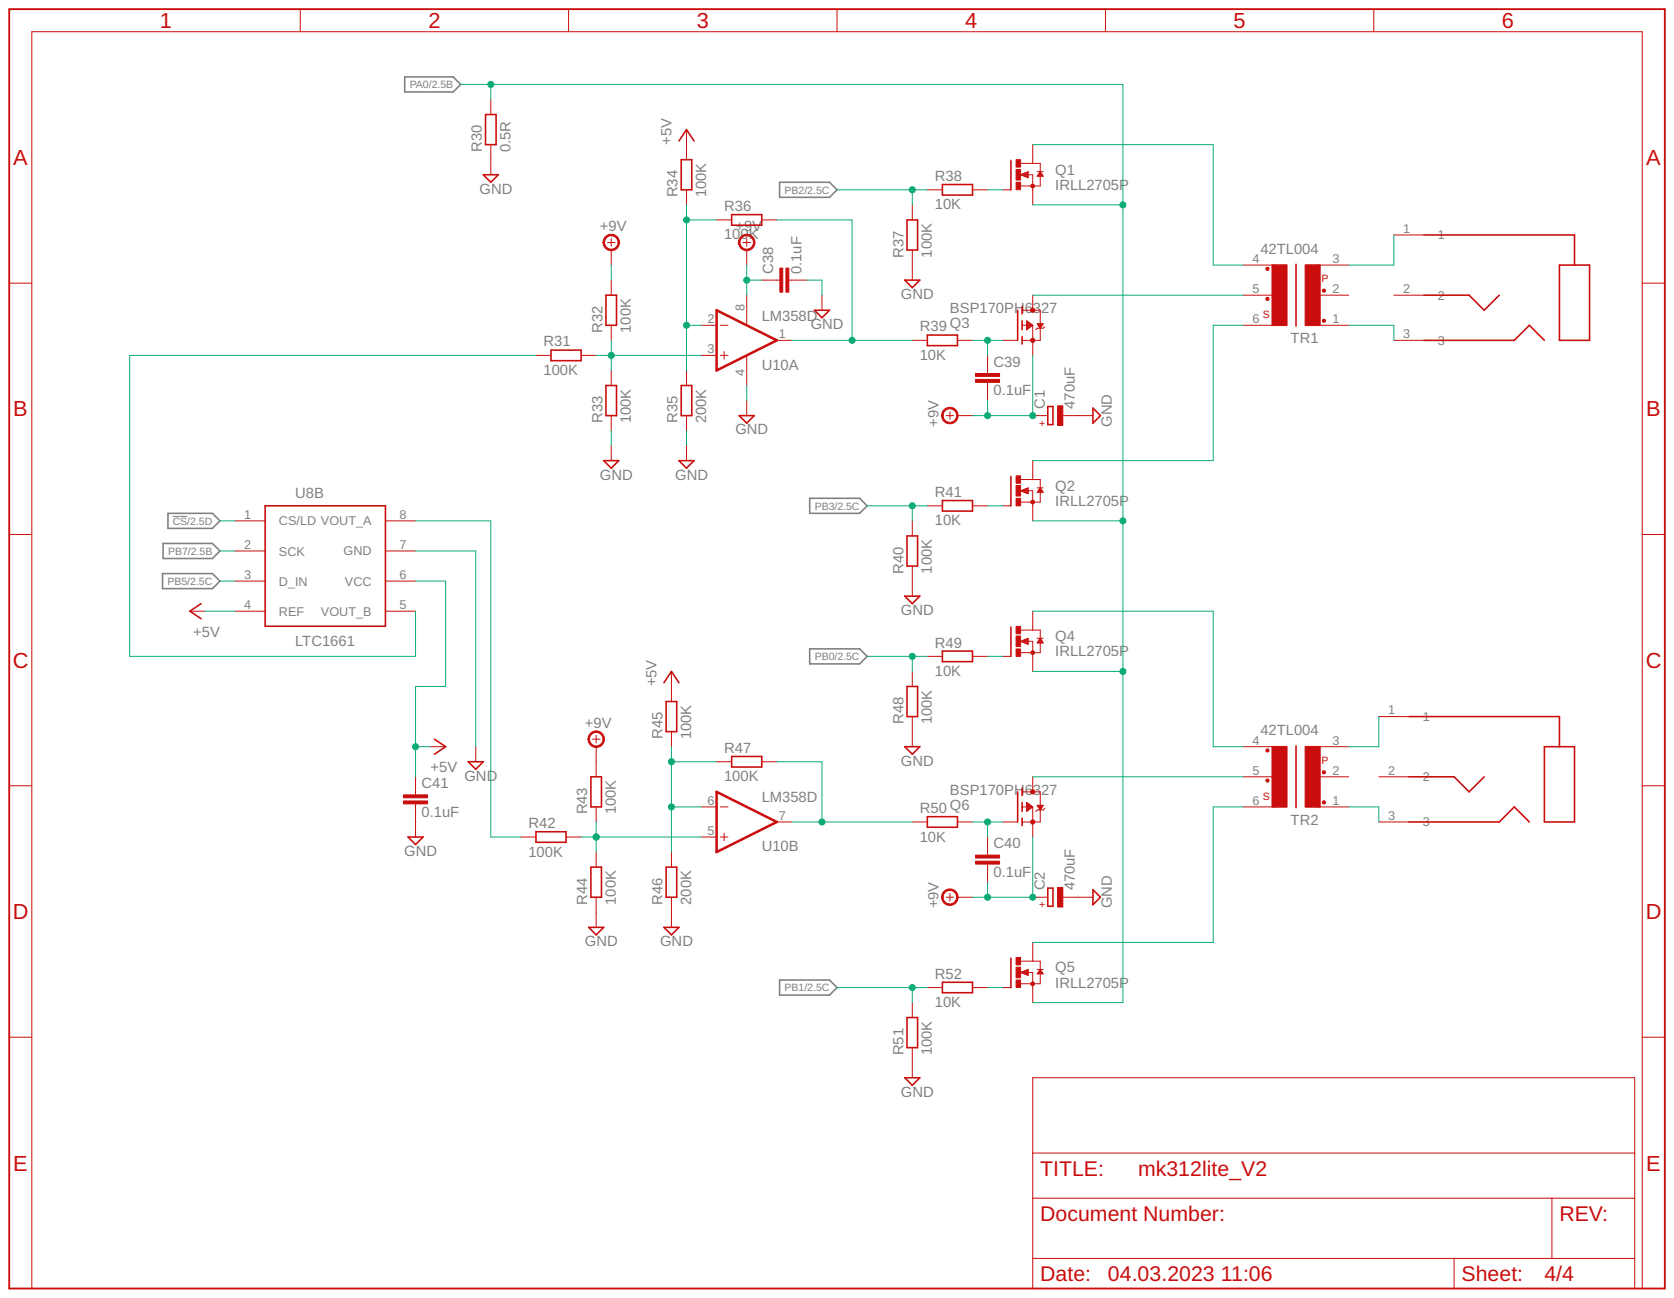
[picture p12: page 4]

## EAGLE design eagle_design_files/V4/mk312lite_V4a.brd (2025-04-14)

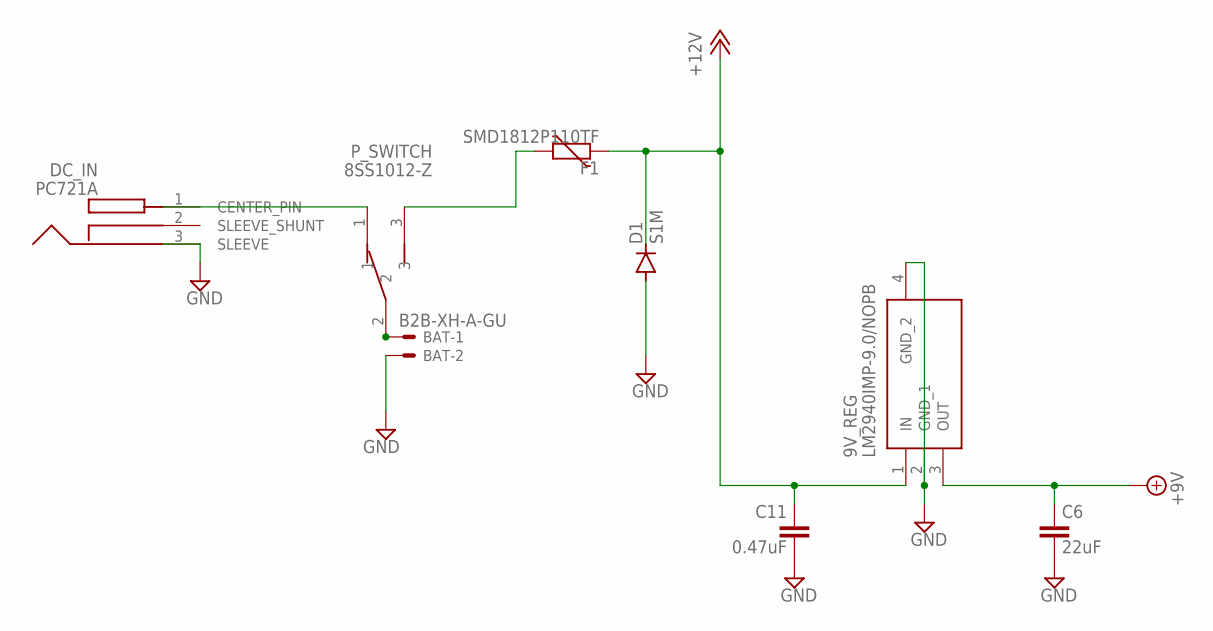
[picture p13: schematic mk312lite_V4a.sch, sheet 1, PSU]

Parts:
9V_REG: LM2940IMP-9.0/NOPB; SOT230P700X180-4N
BAT: B2B-XH-A-GU; JST-XH-02-PACKAGE-LONG-PAD
C6: 22uF; C1206
C11: 0.47uF; C0805
D1: S1M; SMA
DC_IN: PC721A
F1: SMD1812P110TF; CT/CN1812
P_SWITCH: 8SS1012-Z; 8SS1012Z

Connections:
+9V: 9V_REG.3 (OUT), C6.1; also elsewhere on the board
+12V: 9V_REG.1 (IN), C11.1, D1.C, F1.2; also elsewhere on the board
GND: 9V_REG.2 (GND_1), 9V_REG.4 (GND_2), BAT.2, C6.2, C11.2, D1.A, DC_IN.3 (SLEEVE); also elsewhere on the board
unnamed: BAT.1, P_SWITCH.2
unnamed: F1.1, P_SWITCH.3
unnamed: DC_IN.1 (CENTER_PIN), P_SWITCH.1

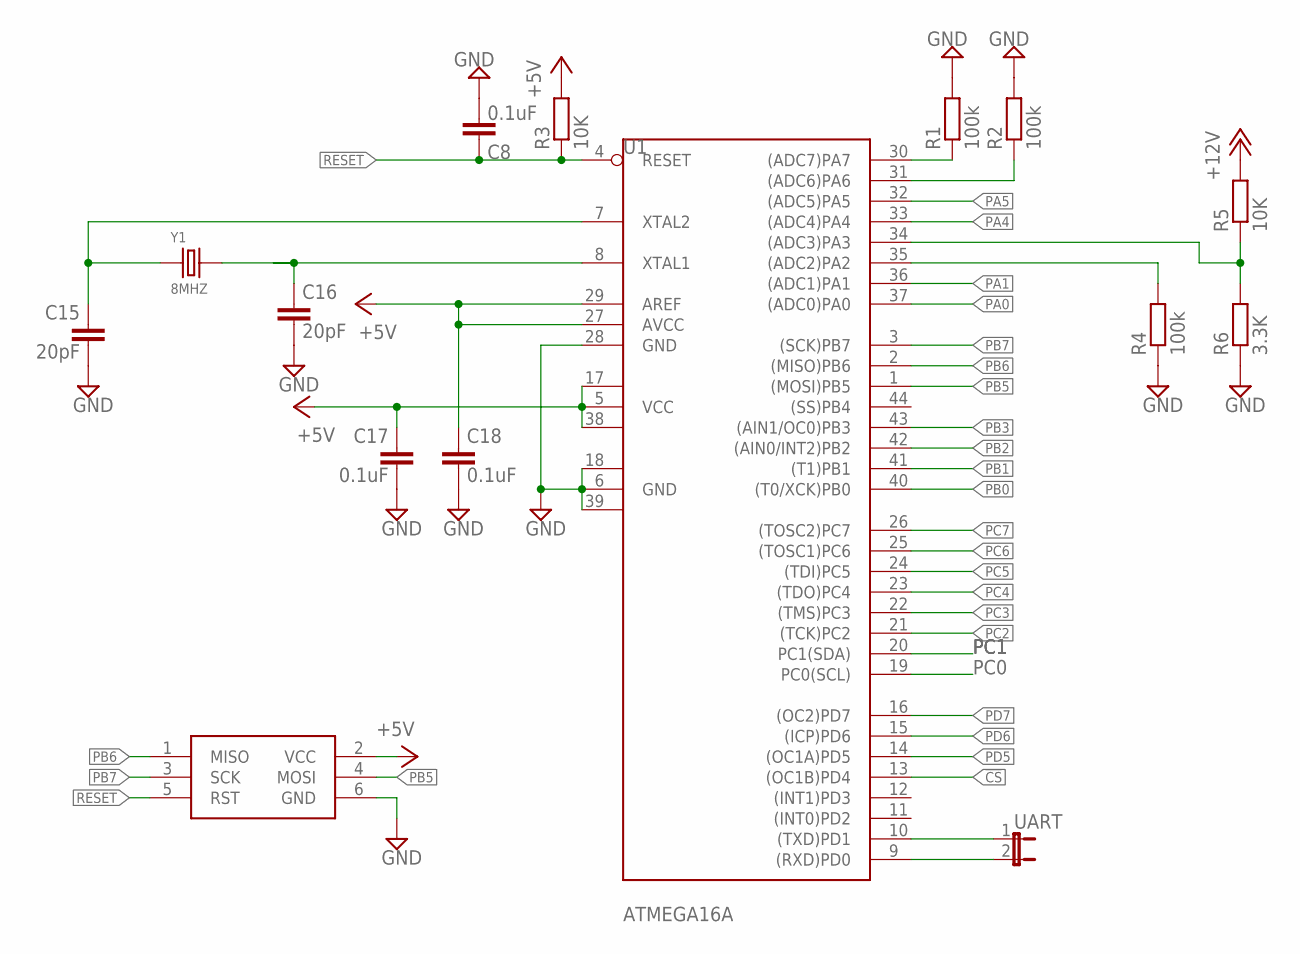
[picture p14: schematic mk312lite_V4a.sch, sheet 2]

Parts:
C8, C17, C18: 0.1uF; C0805
C15, C16: 20pF; C0603
ISP1: AVRISP-6; AVRISP
R1, R2, R4: 100k; R0805
R3, R5: 10K; R0805
R6: 3.3K; R0805
U1: ATMEGA16A; TQFP44
UART: JP1E; JP1
Y1: 8MHZ; X2-SMD-5.0X3.2X1.3MM

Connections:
!CS: U1.13 ((OC1B)PD4); also elsewhere on the board
+5V: C17.1, C18.1, ISP1.2 (VCC), R3.2, U1.5 (VCC), U1.17 (VCC1), U1.27 (AVCC), U1.29 (AREF), U1.38 (VCC2); also elsewhere on the board
+12V: R5.2; also elsewhere on the board
GND: C8.2, C15.2, C16.2, C17.2, C18.2, ISP1.6 (GND), R1.2, R2.2, R4.1, R6.1, U1.6 (GND), U1.18 (GND1), U1.28 (GND), U1.39 (GND2); also elsewhere on the board
unnamed: R5.1, R6.2, U1.34 ((ADC3)PA3)
unnamed: R4.2, U1.35 ((ADC2)PA2)
unnamed: R1.1, U1.30 ((ADC7)PA7)
unnamed: C16.1, U1.8 (XTAL1), Y1.2
unnamed: R2.1, U1.31 ((ADC6)PA6)
unnamed: U1.10 ((TXD)PD1), UART.1
unnamed: U1.9 ((RXD)PD0), UART.2
unnamed: C15.1, U1.7 (XTAL2), Y1.1
PA0: U1.37 ((ADC0)PA0); also elsewhere on the board
PA1: U1.36 ((ADC1)PA1); also elsewhere on the board
PA4: U1.33 ((ADC4)PA4); also elsewhere on the board
PA5: U1.32 ((ADC5)PA5); also elsewhere on the board
PB0: U1.40 ((T0/XCK)PB0); also elsewhere on the board
PB1: U1.41 ((T1)PB1); also elsewhere on the board
PB2: U1.42 ((AIN0/INT2)PB2); also elsewhere on the board
PB3: U1.43 ((AIN1/OC0)PB3); also elsewhere on the board
PB5: ISP1.4 (MOSI), U1.1 ((MOSI)PB5); also elsewhere on the board
PB6: ISP1.1 (MISO), U1.2 ((MISO)PB6)
PB7: ISP1.3 (SCK), U1.3 ((SCK)PB7); also elsewhere on the board
PC0: U1.19 (PC0(SCL)); also elsewhere on the board
PC1: U1.20 (PC1(SDA)); also elsewhere on the board
PC2: U1.21 ((TCK)PC2); also elsewhere on the board
PC3: U1.22 ((TMS)PC3); also elsewhere on the board
PC4: U1.23 ((TDO)PC4); also elsewhere on the board
PC5: U1.24 ((TDI)PC5); also elsewhere on the board
PC6: U1.25 ((TOSC1)PC6); also elsewhere on the board
PC7: U1.26 ((TOSC2)PC7); also elsewhere on the board
PD5: U1.14 ((OC1A)PD5); also elsewhere on the board
PD6: U1.15 ((ICP)PD6); also elsewhere on the board
PD7: U1.16 ((OC2)PD7); also elsewhere on the board
RESET: C8.1, ISP1.5 (RST), R3.1, U1.4 (RESET)

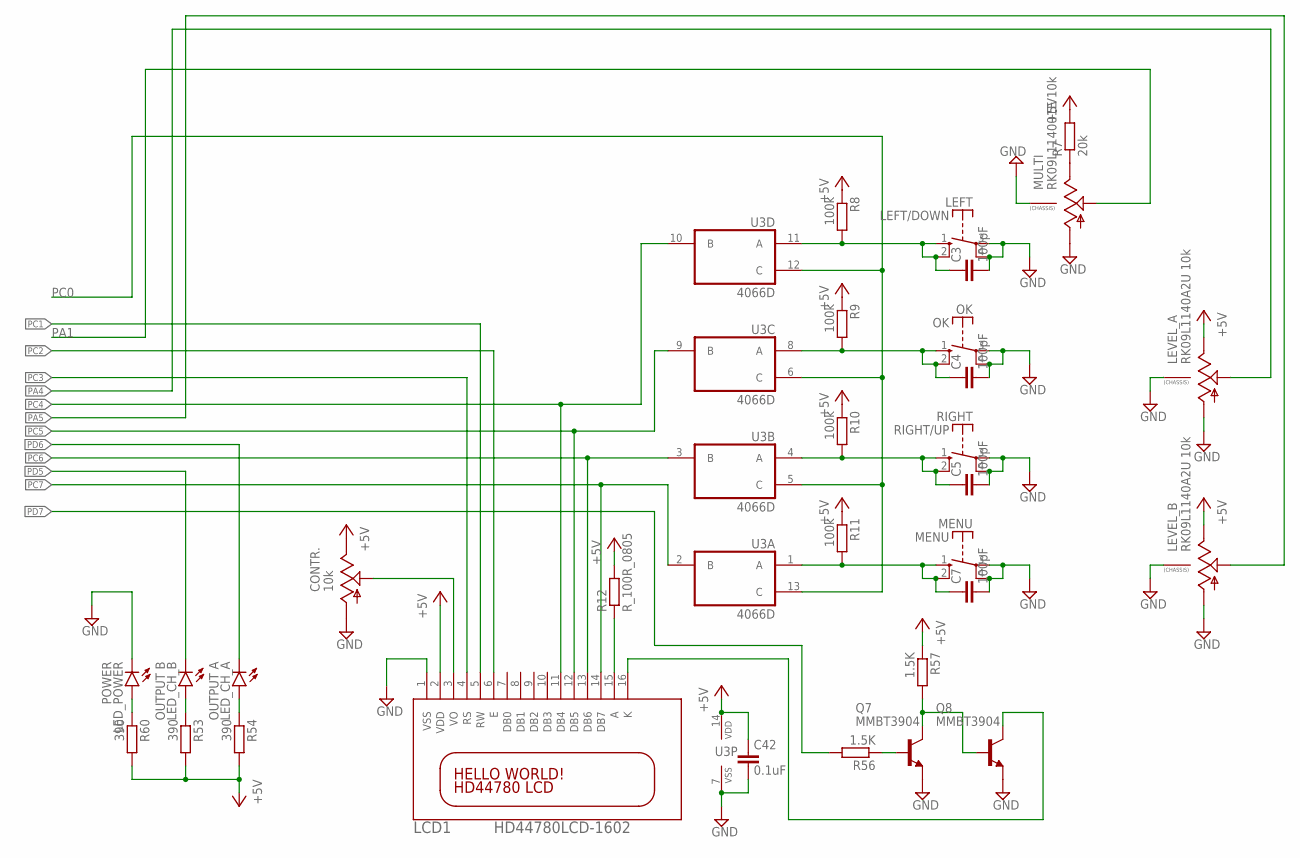
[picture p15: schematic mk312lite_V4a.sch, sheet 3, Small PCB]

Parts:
C3, C4, C5, C7: 100pF; C0805
C42: 0.1uF; C0805
CONTR.: 10k; B25P
LCD1: HD44780LCD-1602; LCD1602
LED_CH_A: OUTPUT A; LED3MM
LED_CH_B: OUTPUT B; LED3MM
LED_POWER: POWER; LED3MM
LEFT: LEFT/DOWN; DTE6K
LEVEL_A: RK09L1140A2U 10k; 9MM_SNAP-IN_POT
LEVEL_B: RK09L1140A2U 10k; 9MM_SNAP-IN_POT
MENU: MENU; DTE6K
MULTI: RK09L114001E 10k; 9MM_SNAP-IN_POT
OK: OK; DTE6K
Q7, Q8: MMBT3904; SOT23-BEC
R7: 20k; R0805
R8, R9, R10, R11: 100k; R0805
R12: R_100R_0805; R0805
R53, R54, R60: 390; R0805
R56, R57: 1.5K; R0805
RIGHT: RIGHT/UP; DTE6K
U3: 4066D; SO14

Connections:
+5V: C42.1, CONTR..E, LCD1.2 (VDD), LEVEL_A.3 (E), LEVEL_B.3 (E), R7.2, R8.1, R9.1, R10.1, R11.1, R12.2, R53.2, R54.2, R57.1, R60.2, U3.14 (VDD); also elsewhere on the board
GND: C3.2, C4.2, C5.2, C7.2, C42.2, CONTR..A, LCD1.1 (VSS), LED_POWER.K (C), LEFT.3, LEFT.4, LEVEL_A.1 (A), LEVEL_A.CHASSIS2, LEVEL_B.1 (A), LEVEL_B.CHASSIS2, MENU.3, MENU.4, MULTI.1 (A), MULTI.CHASSIS2, OK.3, OK.4, Q7.E, Q8.E, RIGHT.3, RIGHT.4, U3.7 (VSS); also elsewhere on the board
unnamed: MULTI.3 (E), R7.1
unnamed: C4.1, OK.1 (S), OK.2 (S), R9.2, U3.8 (A)
unnamed: C3.1, LEFT.1 (S), LEFT.2 (S), R8.2, U3.11 (A)
unnamed: C5.1, R10.2, RIGHT.1 (S), RIGHT.2 (S), U3.4 (A)
unnamed: LED_CH_B.A, R53.1
unnamed: LED_CH_A.A, R54.1
unnamed: CONTR..S, LCD1.3 (VO)
unnamed: LCD1.15 (A), R12.1
unnamed: C7.1, MENU.1 (S), MENU.2 (S), R11.2, U3.1 (A)
unnamed: LED_POWER.A, R60.1
unnamed: Q7.B, R56.1
unnamed: Q7.C, Q8.B, R57.2
unnamed: LCD1.16 (K), Q8.C
PA1: MULTI.2 (S); also elsewhere on the board
PA4: LEVEL_A.2 (S); also elsewhere on the board
PA5: LEVEL_B.2 (S); also elsewhere on the board
PC0: U3.5 (C), U3.6 (C), U3.12 (C), U3.13 (C); also elsewhere on the board
PC1: LCD1.5 (RW); also elsewhere on the board
PC2: LCD1.6 (E); also elsewhere on the board
PC3: LCD1.4 (RS); also elsewhere on the board
PC4: LCD1.11 (DB4), U3.10 (B); also elsewhere on the board
PC5: LCD1.12 (DB5), U3.9 (B); also elsewhere on the board
PC6: LCD1.13 (DB6), U3.3 (B); also elsewhere on the board
PC7: LCD1.14 (DB7), U3.2 (B); also elsewhere on the board
PD5: LED_CH_B.K (C); also elsewhere on the board
PD6: LED_CH_A.K (C); also elsewhere on the board
PD7: R56.2; also elsewhere on the board

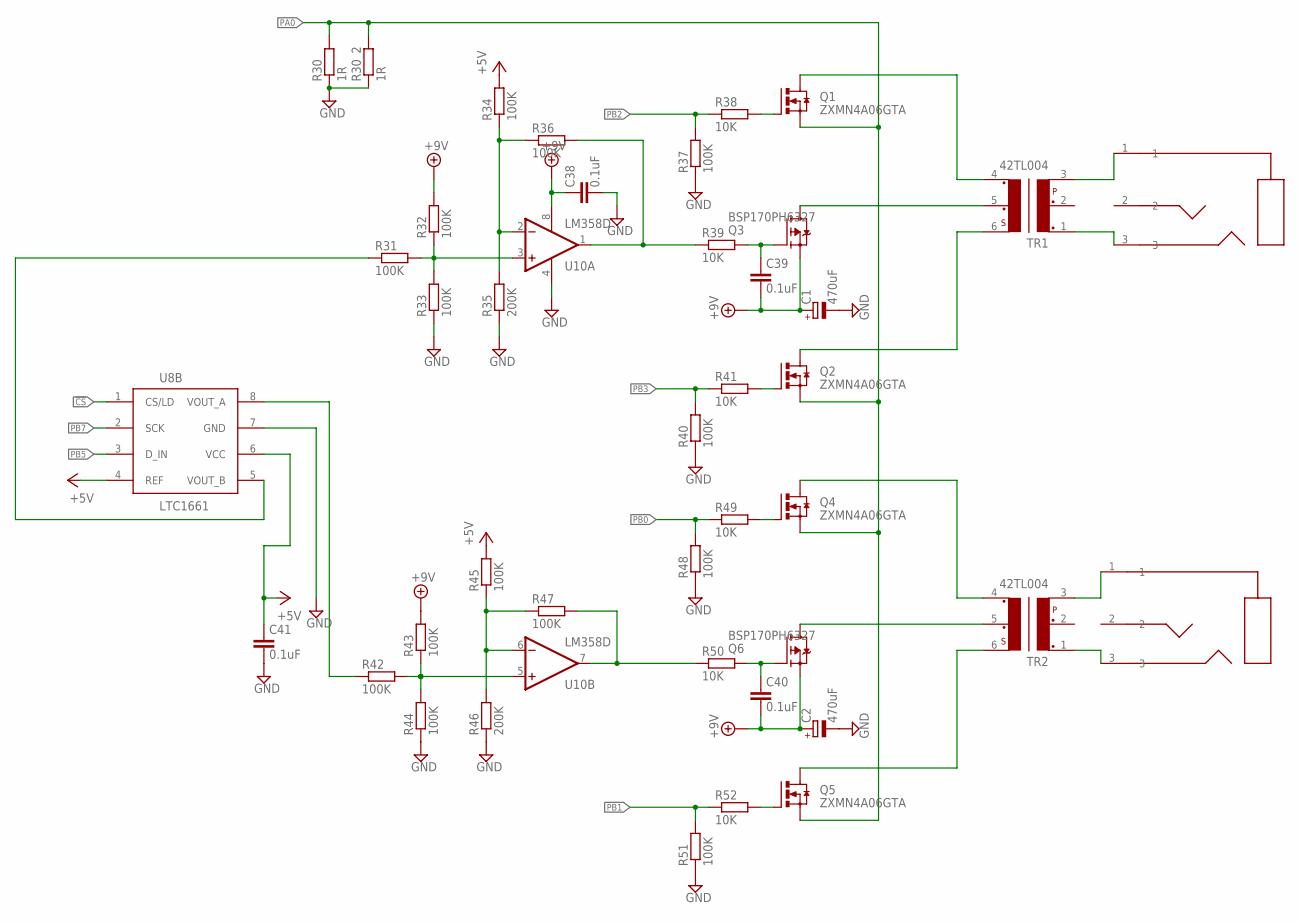
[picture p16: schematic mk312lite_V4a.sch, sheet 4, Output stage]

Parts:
C1, C2: 470uF; 150CLZ-1010
C38, C39, C40, C41: 0.1uF; C0805
CHAN_A: PJ-301C
CHAN_B: PJ-301C
Q1, Q2, Q4, Q5: ZXMN4A06GTA; SOT223
Q3, Q6: BSP170PH6327; SOT230P700X180-4N
R30, R30_2: 1R; R1206
R31, R32, R33, R34, R36, R37, R40, R42, R43, R44, R45, R47, R48, R51: 100K; R0805
R35, R46: 200K; R0805
R38, R39, R41, R49, R50, R52: 10K; R0805
TR1, TR2: 42TL004; 42TL
U8B: LTC1661; MSOP8
U10: LM358D; SO08

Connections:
!CS: U8B.1 (CS/LD); also elsewhere on the board
+5V: C41.1, R34.2, R45.2, U8B.4 (REF), U8B.6 (VCC); also elsewhere on the board
+9V: C1.+, C2.+, C38.1, C39.2, C40.2, Q3.3 (S), Q6.3 (S), R32.2, R43.2, U10.8 (V+); also elsewhere on the board
GND: C1.-, C2.-, C38.2, C41.2, R30.1, R30_2.1, R33.1, R35.1, R37.1, R40.1, R44.1, R46.1, R48.1, R51.1, U8B.7 (GND), U10.4 (V-); also elsewhere on the board
unnamed: Q3.2 (D), Q3.4 (D), TR1.5
unnamed: Q6.2 (D), Q6.4 (D), TR2.5
unnamed: CHAN_A.1, TR1.3
unnamed: CHAN_A.3, TR1.1
unnamed: CHAN_B.1, TR2.3
unnamed: CHAN_B.3, TR2.1
unnamed: Q1.1 (G), R38.2
unnamed: Q2.1 (G), R41.2
unnamed: C39.1, Q3.1 (G), R39.2
unnamed: R31.2, R32.1, R33.2, U10.3 (+IN)
unnamed: Q4.1 (G), R49.2
unnamed: Q5.1 (G), R52.2
unnamed: C40.1, Q6.1 (G), R50.2
unnamed: R42.2, R43.1, R44.2, U10.5 (+IN)
unnamed: Q1.2 (D), Q1.4 (D), TR1.4
unnamed: Q4.2 (D), Q4.4 (D), TR2.4
unnamed: Q5.2 (D), Q5.4 (D), TR2.6
unnamed: Q2.2 (D), Q2.4 (D), TR1.6
unnamed: R34.1, R35.2, R36.1, U10.2 (-IN)
unnamed: R45.1, R46.2, R47.1, U10.6 (-IN)
unnamed: R31.1, U8B.5 (VOUT_B)
unnamed: R42.1, U8B.8 (VOUT_A)
PA0: Q1.3 (S), Q2.3 (S), Q4.3 (S), Q5.3 (S), R30.2, R30_2.2; also elsewhere on the board
PB0: R48.2, R49.1; also elsewhere on the board
PB1: R51.2, R52.1; also elsewhere on the board
PB2: R37.2, R38.1; also elsewhere on the board
PB3: R40.2, R41.1; also elsewhere on the board
PB5: U8B.3 (D_IN); also elsewhere on the board
PB7: U8B.2 (SCK); also elsewhere on the board
PFET_A: R36.2, R39.1, U10.1 (OUT)
PFET_B: R47.2, R50.1, U10.7 (OUT)

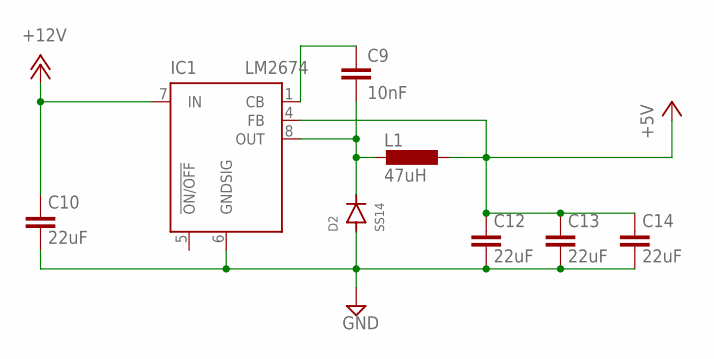
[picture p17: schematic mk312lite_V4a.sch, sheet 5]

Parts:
C9: 10nF; C0805
C10, C12, C13, C14: 22uF; C1206
D2: SS14; SMA
IC1: LM2674; SO08
L1: 47uH; SMNR4030-151MT

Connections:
+5V: C12.1, C13.1, C14.1, IC1.4 (FB), L1.2; also elsewhere on the board
+12V: C10.1, IC1.7 (IN); also elsewhere on the board
GND: C10.2, C12.2, C13.2, C14.2, D2.A, IC1.6 (GNDSIG); also elsewhere on the board
unnamed: C9.1, IC1.1 (CB)
unnamed: C9.2, D2.C, IC1.8 (OUT), L1.1

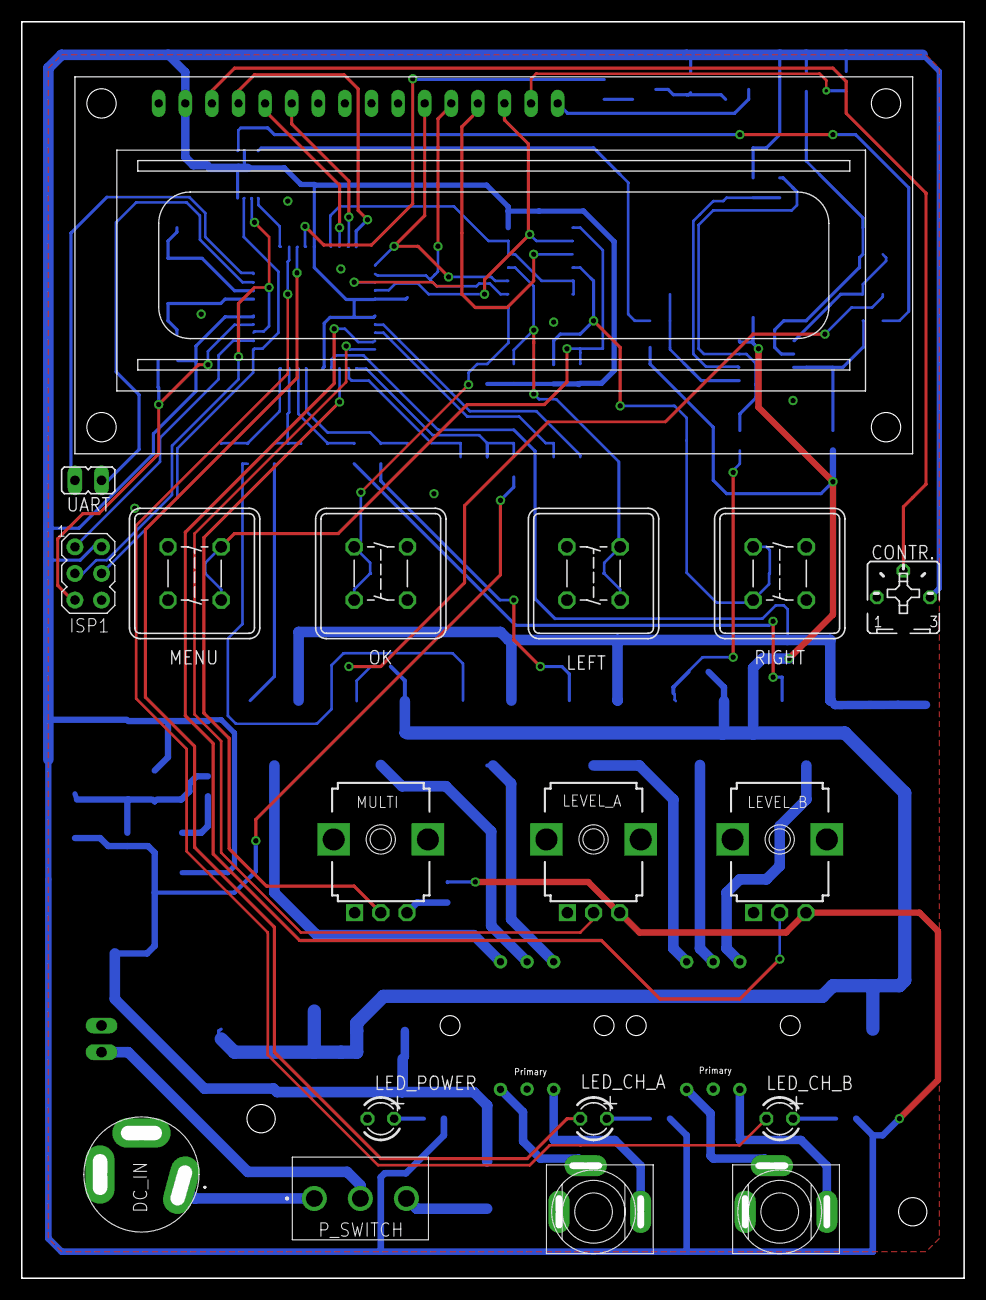
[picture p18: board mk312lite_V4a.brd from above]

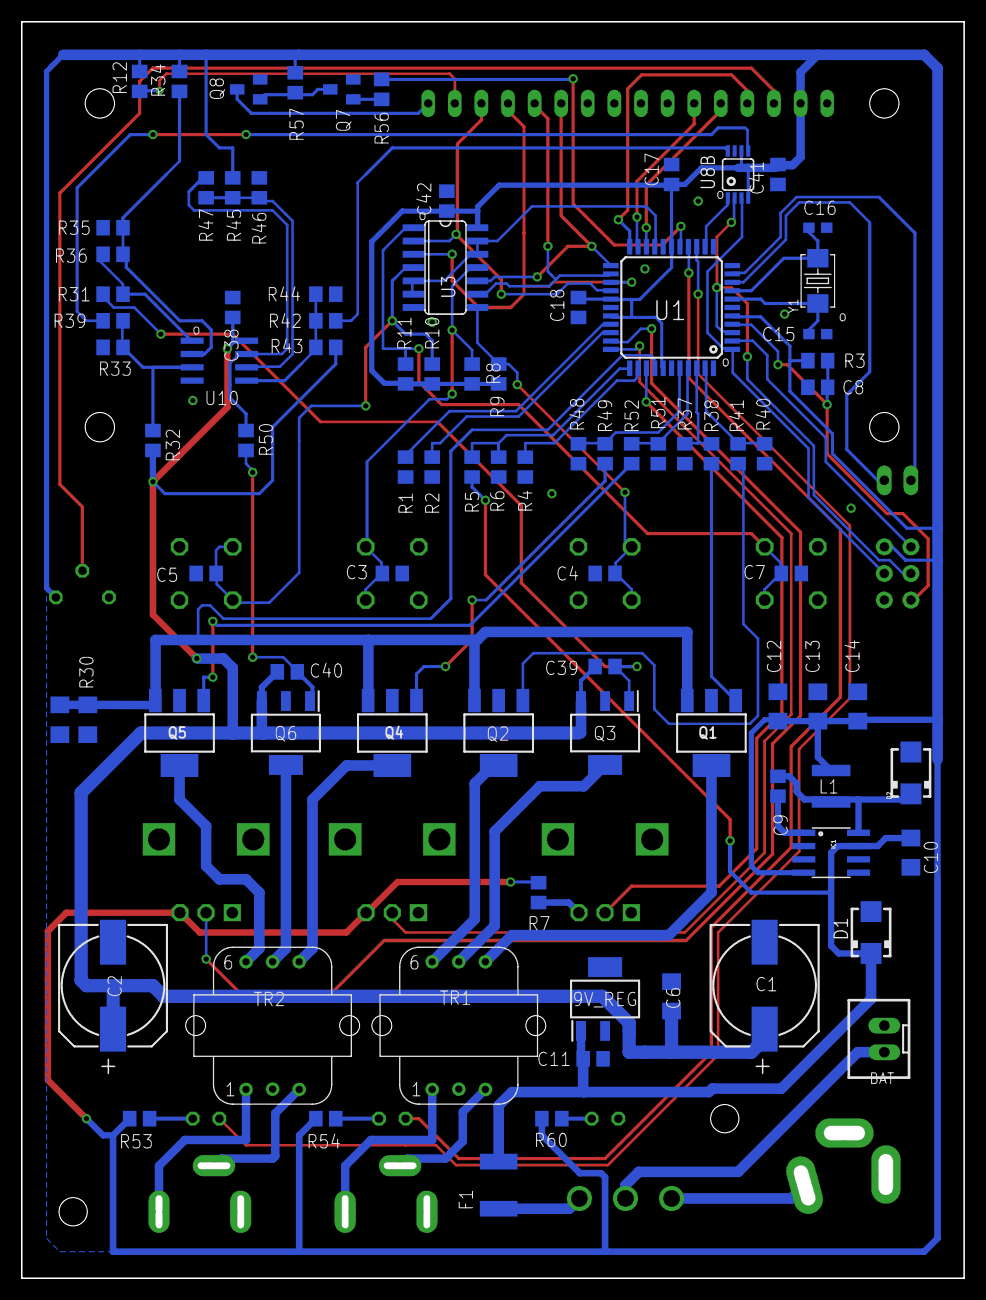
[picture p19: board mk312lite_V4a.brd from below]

Board: 2 copper layers, 90.0 x 120.0 mm, 104 parts (86 on the bottom side), 78 nets.

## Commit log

2023-03-10 Add files via upload
    Makeshift case. Just to give an impression on how it might look like.
2024-01-20 Update and rename JLC_CPT.csv to JLC_CPL.csv
    [JLC_CPL.csv]

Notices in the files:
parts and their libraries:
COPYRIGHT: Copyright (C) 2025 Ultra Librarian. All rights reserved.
